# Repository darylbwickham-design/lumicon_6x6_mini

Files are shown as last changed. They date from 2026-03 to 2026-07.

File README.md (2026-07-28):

# Lumi-Con 6×6 Matrix Mini v1.1.0

A 36-key open-source stream controller with an integrated ST7735 TFT display, phone-first device setup, Lumia plugin support, and optional virtual pet features.

This project uses:

- a **Raspberry Pi Pico (RP2040)** to scan the 6×6 matrix
- an **ESP8266** to handle the TFT, Wi-Fi, HTTP API, and Lumia communication
- a **Lumia plugin** to receive key events, expose variables, and send display / pet actions back to the device

---

## What it does

### Inputs: device → Lumia

- The Pico scans all 36 keys and sends UART packets to the ESP8266.
- The ESP8266 converts those into Lumia-facing events:
  - **Short press:** `0–35`
  - **Long press:** `36–71` (`key + 36`)
- The ESP8266 posts events to the Lumia plugin listener.

### Display and pet control: Lumia → device

The ESP8266 exposes local HTTP endpoints so Lumia can send text, status updates, clear commands, health checks, and pet actions back to the device.

---

## Recommended current release set

Use this combination as the current baseline:

- **Pico firmware:** `6x6_test_pico.ino` or UF2 built from it
- **ESP firmware:** `lumicon_6x6_mini_v1_1_4.ino`
- **Lumia plugin:** `6x6_matrix_mini_v1_1_3.lumiaplugin`

### Plugin naming note

Older project history refers to the integrated plugin as **v5.2**. That package is effectively the **1.0.0** public baseline for the newer `6x6 matrix mini` plugin line.

If you are using the newer plugin packages, treat these as the current progression:

- `1.0.0` = old integrated `v5.2`
- `1.1.x` = newer `6x6 matrix mini` plugin line

---

## Main features

### Easy phone-based setup

On first boot, the ESP firmware can create a setup access point named **`Lumi-Con-Setup`**.

Use a mobile phone for first-time Wi-Fi setup, not the streaming PC or desktop browser. On your phone, connect to the setup Wi-Fi network, then tap the phone's Wi-Fi sign-in notification or open the phone's browser at:

`http://192.168.4.1`

From there you can join the device to your Wi-Fi network without editing the firmware source.

### Browser-based plugin host pairing

Once the device is already on your normal Wi-Fi network, you can set the Lumia/plugin host from any browser on the same network instead of recompiling the ESP sketch.

Use:

`http://<device-ip>/plugin?host=<pc-ip>`

This host is stored by the ESP and reused after reboot.

### TFT display actions

The Lumia plugin can send:

- **Display: Add Line**
- **Display: Set Status**
- **Display: Clear**

This is useful for:

- scene/status text
- alerts
- chat-style output
- debugging
- custom stream messages

### Virtual pet support

The platform includes an optional virtual pet system.

The current plugin supports these pet actions:

- `status`
- `sync`
- `feed`
- `play`
- `clean`
- `sleep`
- `med`
- `discipline`
- `reset`

The plugin also exposes pet variables for overlays, alerts, and automations.

### More reliable idle handling

The current plugin line performs a silent health check using `/status?silent=1` before marking the device offline, which helps avoid false disconnects when the device is simply idle.

### Multiple runtime modes

The current ESP firmware supports:

- **Chat mode**
- **noPet Debug mode**
- **Pet mode**
- **LCD Only Mode**

---

## Repository layout

At the time of writing, the public repository includes top-level folders for **3d files**, **Docs**, **Firmware**, and **Plugins/v5.2**. This README is written around the latest firmware and plugin files reviewed for this update, even where the live public repo still shows older packaging and README text. 

Recommended repo structure going forward:

- `Firmware/` for Pico and ESP firmware
- `Plugins/` for Lumia plugin packages and source
- `Docs/` for setup docs, changelogs, and release notes
- `3d files/` for enclosure and print assets

---

## Hardware overview

### Pico ↔ 6×6 matrix

The Pico scans the matrix.

Current Pico test firmware pin mapping:

#### Rows (inputs with pullups)
- `R0 -> GP12`
- `R1 -> GP1`
- `R2 -> GP2`
- `R3 -> GP3`
- `R4 -> GP4`
- `R5 -> GP5`

#### Columns (outputs)
- `C0 -> GP6`
- `C1 -> GP7`
- `C2 -> GP8`
- `C3 -> GP9`
- `C4 -> GP10`
- `C5 -> GP11`

### Pico → ESP8266 UART

- `Pico GP0 (TX) -> ESP RX / GPIO3`
- `Pico GND -> ESP GND`
- Optional: `1k` resistor in series on the TX line

### ESP8266 → ST7735 TFT (SPI)

Current ESP firmware pin mapping:

- `TFT VCC -> 3V3`
- `TFT GND -> GND`
- `TFT SCK -> D5 / GPIO14`
- `TFT MOSI -> D7 / GPIO13`
- `TFT CS -> D2 / GPIO4`
- `TFT DC -> D1 / GPIO5`
- `TFT RST -> ESP RST` recommended

### Important flashing note

Disconnect `Pico GP0 (TX) -> ESP RX (GPIO3)` while uploading firmware to the ESP8266.

---

## Arduino IDE setup

### 1) Install Arduino IDE

Download from:

`https://www.arduino.cc/en/software`

### 2) Add board manager URLs

In Arduino IDE, open:

`File -> Preferences -> Additional Boards Manager URLs`

Add:

#### ESP8266
`http://arduino.esp8266.com/stable/package_esp8266com_index.json`

#### Pico / RP2040 (Earle Philhower)
`https://github.com/earlephilhower/arduino-pico/releases/download/global/package_rp2040_index.json`

### 3) Install board packages

Open:

`Tools -> Board -> Boards Manager`

Install:

- **ESP8266 by ESP8266 Community**
- **Raspberry Pi Pico/RP2040 by Earle Philhower**

### 4) Install required libraries for the ESP8266 firmware

Install through **Sketch -> Include Library -> Manage Libraries**:

- **WiFiManager**
- **Adafruit GFX Library**
- **Adafruit ST7735 and ST7789 Library**

The Pico test firmware does not require extra third-party Arduino libraries beyond the RP2040 board package.

---

## Flashing the firmware

### 1) Flash the Pico

Flash your current Pico matrix-scanner firmware first.

If you use a UF2 build:

1. Hold **BOOTSEL** while plugging the Pico into USB
2. The Pico appears as a USB drive
3. Drag and drop the UF2 file

If you use source:

- Open `6x6_test_pico.ino`
- Select your Pico board
- Upload normally

### 2) Flash the ESP8266

1. Disconnect `Pico GP0 -> ESP RX`
2. Open `lumi_con_esp_integrated_0_4_2.ino`
3. Select the correct ESP8266 board
4. Upload the firmware
5. Reconnect `Pico GP0 -> ESP RX`

---

## First-time device setup

### Step 1: connect the ESP to Wi-Fi

1. Power the device
2. On your mobile phone, open Wi-Fi settings and connect to the access point:
   - **`Lumi-Con-Setup`**
3. Tap the phone's Wi-Fi sign-in notification. If it does not appear, open the phone's browser and go to:
   - **`http://192.168.4.1`**
4. Select your Wi-Fi network and enter the password
5. Save
6. The ESP reboots and the display shows its IP address

Use the phone for this captive-portal step. A desktop or streaming PC browser is more likely to stay on your normal network and miss the device setup page.

### Step 2: install and configure the Lumia plugin

Install the current Lumia plugin package.

Recommended current plugin:

- `6x6_matrix_mini_v1_1_3.lumiaplugin`

In Lumia plugin settings:

- **Enable Listener**: `ON`
- **Listen Port**: `8787`
- **Shared Secret**: blank unless you intentionally set one in firmware
- **ESP Base URL**: set this to your device address, for example:
  - `http://192.168.1.50`

Recommended defaults:

- **ESP UI Mode**: `legacy_get`
- **Status Path**: `/status`
- **Pet Path**: `/pet`

### Step 3: pair the device with the plugin host

After phone Wi-Fi setup is finished and the device shows its IP address, run this from a browser on the same network:

`http://<device-ip>/plugin?host=<pc-ip>`

Example:

`http://192.168.1.50/plugin?host=192.168.1.87`

This tells the ESP where the Lumia plugin listener is running.

### Step 4: confirm the device is responding

Useful test URLs:

- `http://<device-ip>/health`
- `http://<device-ip>/plugin`
- `http://<device-ip>/msg?t=Hello`
- `http://<device-ip>/status?t=OK`
- `http://<device-ip>/clear`
- `http://<device-ip>/pet?action=status`

---

## Current HTTP API

The current ESP firmware supports these user-facing routes:

- `GET /`
- `GET /msg?t=...`
- `GET /status?t=...`
- `GET /status?silent=1`
- `GET /clear`
- `POST /ui`
- `GET /health`
- `GET /plugin`
- `GET /plugin?host=<pc-ip>`
- `GET /plugin?clear=1`
- `GET /pet?action=status|sync|feed|play|clean|sleep|med|toggleSleep|discipline|reset`

---

## Boot behavior and modes

Current boot-key behavior in the ESP firmware:

- Hold **Pico key 0** at boot -> reset Wi-Fi settings and restart
- Hold **Pico key 1** at boot -> Chat mode
- Hold **Pico key 2** at boot -> noPet Debug mode
- Hold **Pico key 35** at boot -> Pet mode

Current runtime modes include:

- **Chat mode**
- **noPet Debug mode**
- **Pet mode**
- **LCD Only Mode**

---

## Lumia plugin: what it adds

### Alerts

The current plugin provides:

- **6x6 short**
- **6x6 long**
- **Pet**

### Actions

The current plugin provides:

- **Display: Add Line**
- **Display: Set Status**
- **Display: Clear**
- **Pet Action**

### Useful variables

The plugin exposes device and pet variables, including:

- `{{event}}`
- `{{kind}}`
- `{{key_label}}`
- `{{held_ms}}`
- `{{device_id}}`
- `{{device_ip}}`
- `{{device_rssi}}`
- `{{device_connected}}`
- `{{device_status_text}}`
- `{{pet_stage_name}}`
- `{{pet_hunger}}`
- `{{pet_happiness}}`
- `{{pet_health}}`
- `{{pet_poop}}`
- `{{pet_change_name}}`

---

## Quick usage ideas

- Use **Display: Set Status** for stream state text such as `LIVE`, `BRB`, or scene names.
- Use **Display: Add Line** for scrolling messages, redeems, or now-playing text.
- Use **Pet Action -> status** before updating a pet overlay.
- Use **Pet Action -> sync** after reconnecting the device.
- Use **Pet Action -> clean** when a pet event indicates poop-related state changed.

---

## Troubleshooting

### ESP upload fails

Disconnect `Pico GP0 (TX) -> ESP RX (GPIO3)` while flashing the ESP8266.

### The setup AP does not appear

- Reboot the device
- Use the factory reset boot key path if Wi-Fi credentials need clearing
- Make sure the ESP firmware actually flashed successfully

### TFT stays white or blank

- Check TFT power and SPI wiring
- Wire `TFT RST -> ESP RST`
- If colours are wrong, check the ST7735 tab/init settings in firmware

### Lumia receives nothing

- Make sure the plugin listener is enabled
- Confirm the plugin listen port is `8787` unless intentionally changed
- Confirm the ESP host pairing was set with:
  - `http://<device-ip>/plugin?host=<pc-ip>`
- Confirm the PC and device are on the same LAN

### Lumia can receive key events but cannot send text or pet commands

- Set **ESP Base URL** in plugin settings to the device address
- Check `/health` and `/status` in a browser on the same network after phone setup is complete
- Confirm the device IP did not change after a reboot

### The plugin looks “offline” after idle time

The current plugin line performs one silent health check first. If you still see offline behavior:

- confirm **ESP Base URL** is correct
- confirm **Status Path** is `/status`
- confirm the device responds to:
  - `http://<device-ip>/status?silent=1`

---

## Summary

**Lumi-Con 6×6 Matrix Mini is a 36-key open-source stream controller with an integrated TFT display, phone-first Wi-Fi setup, Lumia plugin support, virtual pet features, and flexible display/status workflows for streams and automations.**

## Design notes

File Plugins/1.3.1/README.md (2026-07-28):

# Lumi-Con 6×6 Mini v1.1.1 — display repair

This is a focused repair for the 1.1 display build. It preserves the existing
hardware wiring, display rotation, Pico packet protocol, key numbers, web
endpoints, EEPROM layout and Lumia listener port.

## What changed

- Celebrations now draw their card once, then update only their moving details.
  The old version cleared and repainted the whole 160×128 TFT every 45 ms,
  which produced the visible black sweep/flash and choppy movement.
- Confetti and Success use animated particles in the unused top and bottom
  bands. Pulse uses a small centred pulse bar. None of those frames redraw the
  message card or the whole TFT.
- The opening frame is drawn immediately when `/celebrate` is called, so the
  browser test button and Lumia action give visible feedback as soon as the
  request arrives.
- The complete normal screen is restored afterwards. This fixes the Pet-mode
  header being blank after a full-screen celebration.
- The matched Lumia plugin verifies the device's JSON confirmation before it
  reports a successful celebration.

## Files

- `Firmware/lumicon_6x6_mini_v1_1_1.ino` — ESP8266 firmware source.
- `Plugin/matrix_6x6_mini_v11-1.3.1.lumiaplugin` — update to the separate
  `matrix_6x6_mini_v11` plugin created for the 1.1 firmware. It does not
  overwrite the original `matrix_6x6_mini` plugin.

## Test after flashing

1. After phone Wi-Fi setup is complete, open the controller address in a
   browser on the same network and run Confetti, Pulse and Success from
   **Test Celebrations**.
2. Each effect should appear immediately, animate without whole-screen black
   flashes, and return to a complete Chat or Pet screen.
3. Run the Lumia **Display: Celebration** action. A bad address, old firmware
   or missing endpoint now reports an error in Lumia instead of a false success.
4. Press a physical key while an effect is playing and confirm its normal Lumia
   key event still arrives.

## Build target

Compile for **LOLIN(WEMOS) D1 mini (clone)** using ESP8266 core **3.1.2** with
WiFiManager, Adafruit GFX and Adafruit ST7735 installed. Flash at offset
`0x000000` as with the previous firmware.

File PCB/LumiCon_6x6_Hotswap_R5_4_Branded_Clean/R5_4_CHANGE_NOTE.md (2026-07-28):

# Lumi-Con 6×6 Matrix Mini R5.4

This revision changes silkscreen only.

## Changes from R5.3

- Increased the 24 J1 pin labels on F.SilkS and B.SilkS from 0.70 mm to 0.80 mm.
- Increased the rear `TOP` label from 0.70 mm to 0.80 mm.
- Increased the rear `J1 PIN 1 = C0` label from 0.70 mm to 0.80 mm.
- Updated the printed revision from R5.3 to R5.4.

Copper, nets, tracks, vias, pads, footprints, drill holes, board outline, mounting holes and component placement are unchanged from the electrically clean R5.3 board.

The supplied DRC report for R5.3 showed:

- 0 unconnected pads
- 0 footprint errors
- 26 silkscreen text-height warnings

R5.4 addresses exactly those 26 warnings. Run KiCad DRC once more before Gerber export to confirm a zero-warning result in your local KiCad version.

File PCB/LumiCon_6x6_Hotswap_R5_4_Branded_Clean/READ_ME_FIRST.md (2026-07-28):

# Lumi-Con 6x6 Matrix Mini R5.3 Branded

This revision is electrically identical to the DRC-clean R5.2 board. Only silkscreen artwork and labels were added.

## Added to front silkscreen

- Simplified monochrome Lumi-Con matrix icon derived from `source_Lumi-Con.png`
- Monochrome `6X6 MATRIX MINI` wordmark derived from `source_6X6_MATRIX_MINI.png`
- `R5.3` revision mark
- J1 pin labels: `C0 R0 C1 R1 C2 R2 C3 R3 C4 R4 C5 R5`

## Added to back silkscreen

- Product/revision identification
- Mirrored J1 pin labels so the connector can be wired from either side
- J1 pin-1 note

## Mechanical

The four existing mounting holes remain unchanged:

- 3.2 mm NPTH clearance holes for M3 screws
- centres: (37.5,37.5), (162.5,37.5), (37.5,162.5), (162.5,162.5) mm in KiCad coordinates

## Before ordering

Open `LumiCon_6x6_Hotswap_R5_3_Branded.kicad_pro`, run KiCad DRC, and inspect both silkscreen layers in the 3D viewer/Gerber viewer. The artwork is confined to the top margin and does not alter copper, pads, drills, or board outline.

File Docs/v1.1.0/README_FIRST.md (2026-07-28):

# Lumi-Con 6×6 Matrix Mini 1.1

This is the compatibility-first upgrade from the supplied 1.0 release.

## What to install

1. Flash `Firmware/ESP8266/FLASH_THIS_lumicon_6x6_mini_v1.1.0.bin` to the
   D1 mini clone at address `0x000000`.
2. Install `Plugin/matrix_6x6_mini-1.3.0.lumiaplugin` in Lumia.
3. Leave the Pico firmware alone unless it needs restoring. Its source and UF2
   are included and remain protocol-compatible with 1.0.
4. Reboot the controller and follow the on-screen boot selector.

Existing Wi-Fi credentials, plugin-host configuration and pet data use the
same EEPROM layout and should survive an ordinary firmware upgrade.

## First Wi-Fi setup

Use a mobile phone, not the streaming PC:

1. Connect the phone to `Lumi-Con-Setup`.
2. Tap the phone's Wi-Fi sign-in notification.
3. If the sign-in page does not open, browse to `192.168.4.1`.
4. Select the normal home/streaming Wi-Fi network and enter its password.

Holding K0 during boot deliberately erases the saved Wi-Fi settings and opens
this setup flow immediately. It no longer makes you sit through a second full
boot before the phone setup screen appears.

## Visible boot controls

Key numbering is row-major: K0 is top-left and K35 is bottom-right.

| Hold during the boot menu | Result |
| --- | --- |
| K0 — top-left | Erase saved Wi-Fi and open phone setup |
| K1 — second key on the top row | Chat mode (also the default) |
| K2 — third key on the top row | noPet diagnostics |
| K35 — bottom-right | Virtual pet mode |

The progress bar must fill before a selection is accepted. If no key is held,
the controller enters Chat mode.

## New in 1.1

- The boot-options page is now actually shown.
- Phone-first Wi-Fi instructions are explicit on the TFT.
- Polished panels, badges, feed cards and wipe transitions replace the crude
  text-only presentation.
- New non-blocking `Confetti`, `Pulse`, and `Success` celebrations.
- Quick, standard, and big-moment celebration lengths.
- Lumia plugin action: **Display: Celebration**.
- Lumia plugin action: **Device: Screen Mode** switches Chat, Pet, and
  Diagnostics at runtime without a reboot.
- A responsive controller panel is available by opening the IP shown on the
  TFT. It can change screen mode, test every celebration, test messages/status,
  clear the feed, and open diagnostic JSON.
- The pet HUD now rotates through all four information pages; the previous
  health/discipline page was unreachable.
- The existing 0–71 key events, 72–93 pet events, endpoints, port 8787,
  display rotation, wiring and pet storage remain compatible.

Read `Docs/UPGRADE_AND_TEST.md` before treating the build as production-tested
on physical hardware. `Docs/BUILD_VALIDATION.md` records the completed compile,
plugin routing, archive, and hardware-integrity checks.

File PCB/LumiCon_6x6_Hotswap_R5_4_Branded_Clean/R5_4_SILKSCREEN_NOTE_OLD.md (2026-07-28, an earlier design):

# R5.3 silkscreen pre-check

- Parentheses balanced: YES
- Electrical object counts unchanged from R5.2: YES

- `(segment` count: 413
- `(via` count: 48
- `(pad` count: 340
- `(footprint` count: 77
- `(net` count: 49

- Front artwork bounds: x 42.0–121.84 mm, y 34.55–39.77 mm
- J1 labels centred at y 39.15 mm, below the header pads.
- No copper, drill, pad, footprint, net, segment, via, or Edge.Cuts objects were modified.

Native KiCad DRC remains the final check.

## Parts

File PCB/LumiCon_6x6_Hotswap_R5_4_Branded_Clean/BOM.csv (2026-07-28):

References | Qty | Value | Footprint | Side
SW1-SW36 | 36 | Kailh CPG151101S11 hot-swap socket | SW_Hotswap_Kailh_1.00u | Bottom
D1-D36 | 36 | 1N4148W | D_SOD-123 | Bottom
J1 | 1 | 1x12 2.54 mm header | PinHeader_1x12_P2.54mm | Through-hole

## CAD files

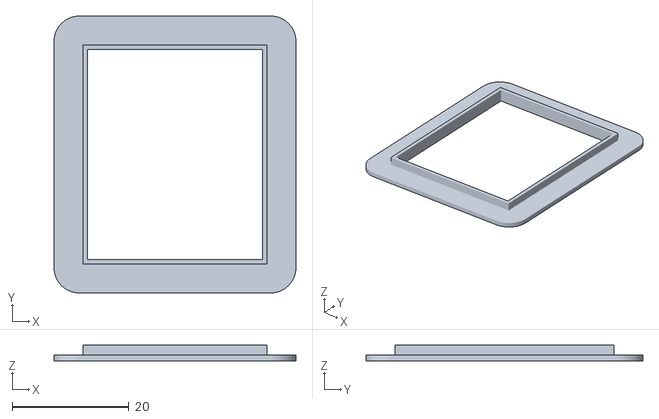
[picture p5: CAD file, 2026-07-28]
3d files/lcd bezel.stl
41.5 x 47.5 x 2.70

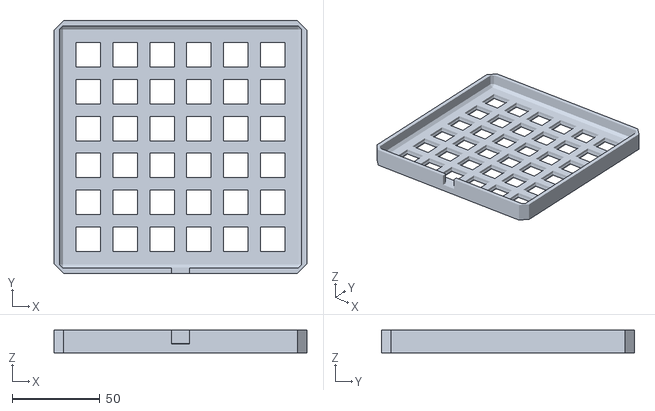
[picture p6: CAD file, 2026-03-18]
PCB/LumiCon_6x6_Hotswap_R5_4_Branded_Clean/6X6 Front V2_reference.stl
144.0 x 144.0 x 13.0

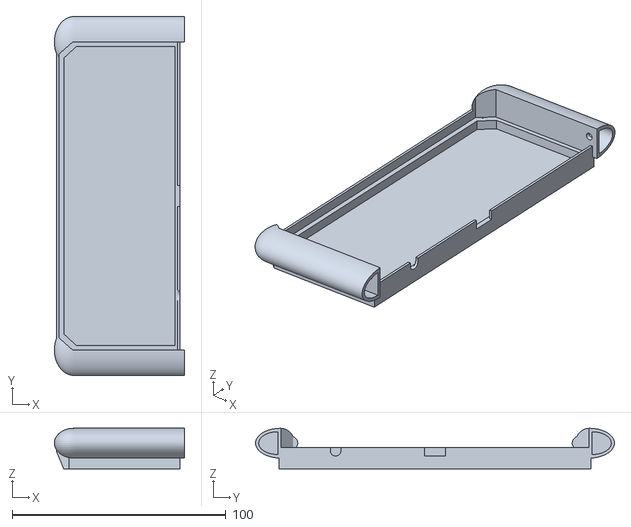
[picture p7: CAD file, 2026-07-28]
3d files/electronics rear v4.stl
61.0 x 168.0 x 19.0

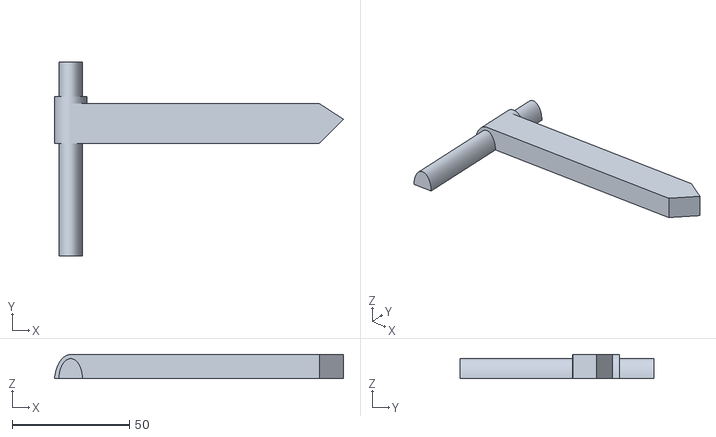
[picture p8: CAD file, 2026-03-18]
3d files/connector leg v2.stl
123.3 x 82.7 x 10.2

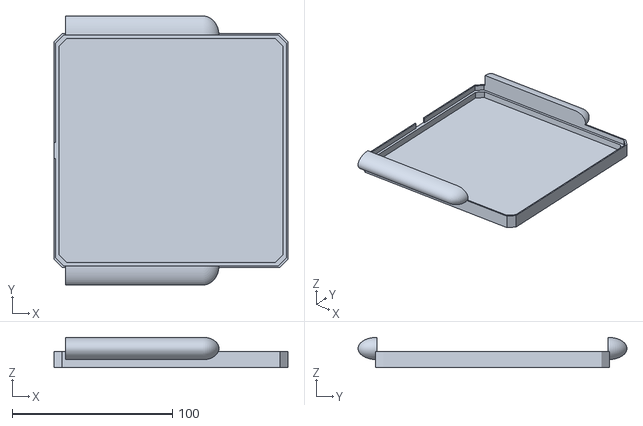
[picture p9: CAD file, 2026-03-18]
3d files/6X6 Rear v2.stl
146.0 x 168.0 x 19.0

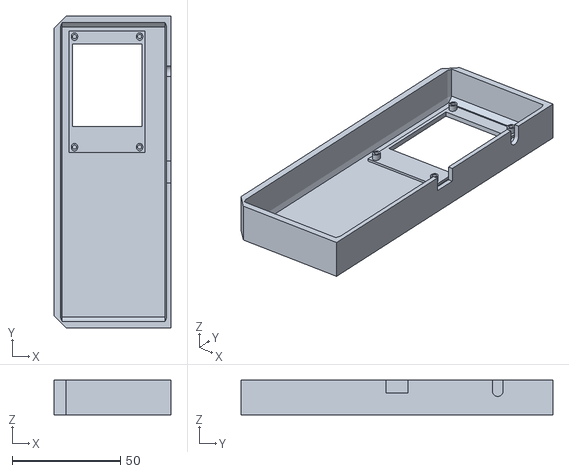
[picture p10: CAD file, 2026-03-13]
3d files/electronics front with lcd v2.stl
54.0 x 144.0 x 16.0

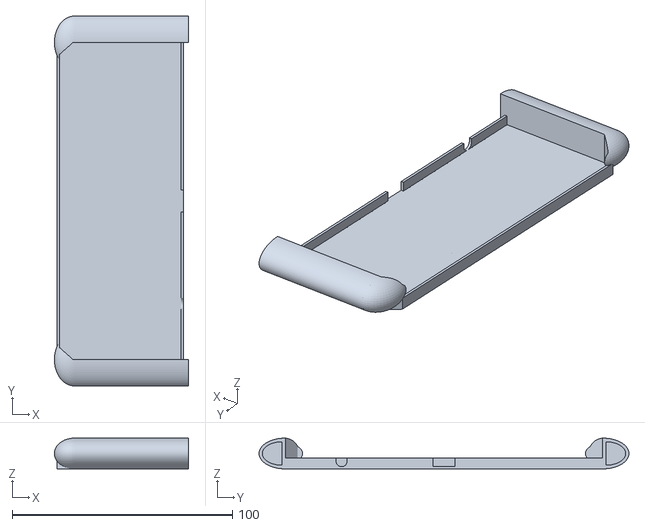
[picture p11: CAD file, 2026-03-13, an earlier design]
3d files/electronics rear v2.stl
61.0 x 168.0 x 14.0

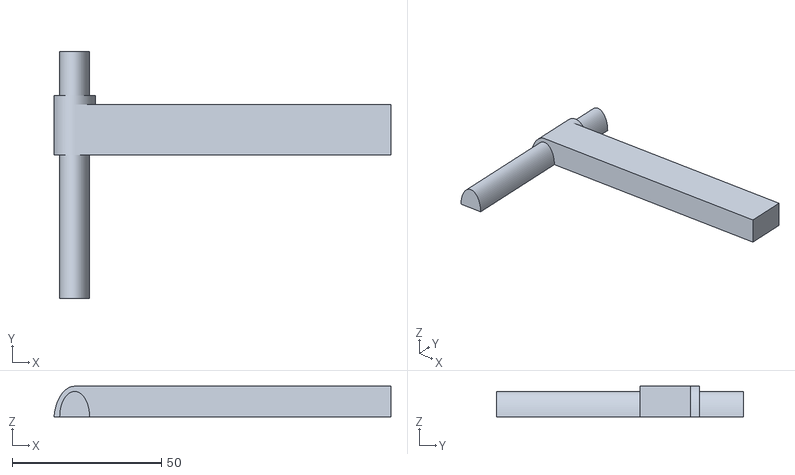
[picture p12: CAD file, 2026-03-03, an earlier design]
3d files/connector leg.stl
112.8 x 82.7 x 10.2

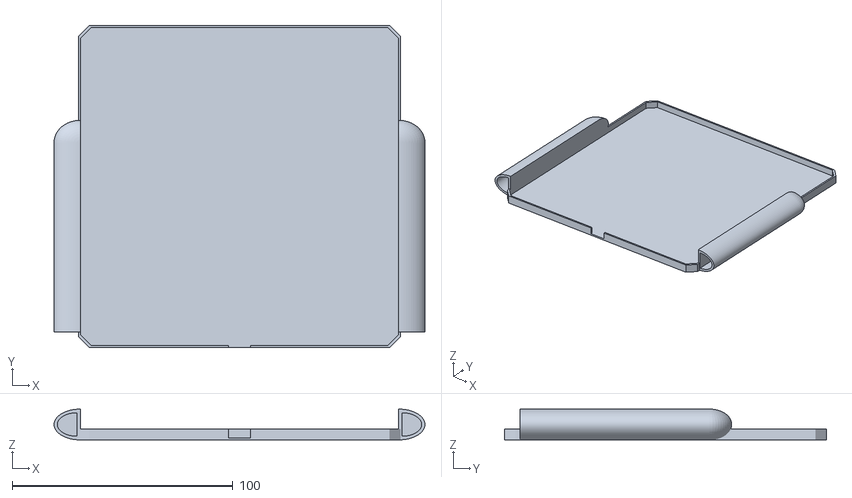
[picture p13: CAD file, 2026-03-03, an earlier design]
3d files/6X6 Rear.stl
168.0 x 146.0 x 14.0

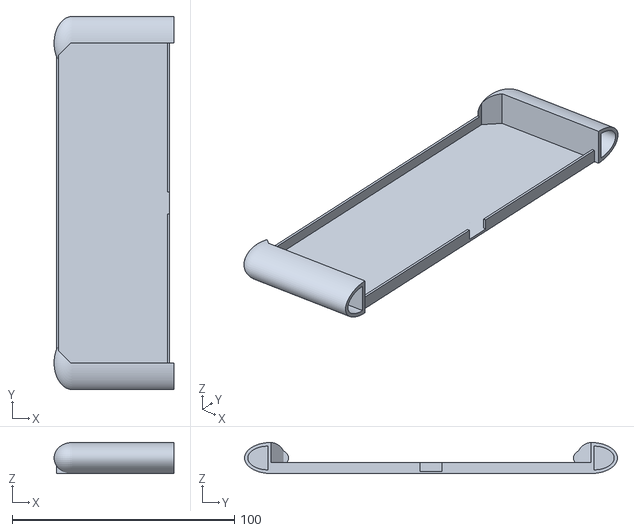
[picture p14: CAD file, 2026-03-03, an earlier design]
3d files/electronics rear.stl
54.0 x 168.0 x 14.0

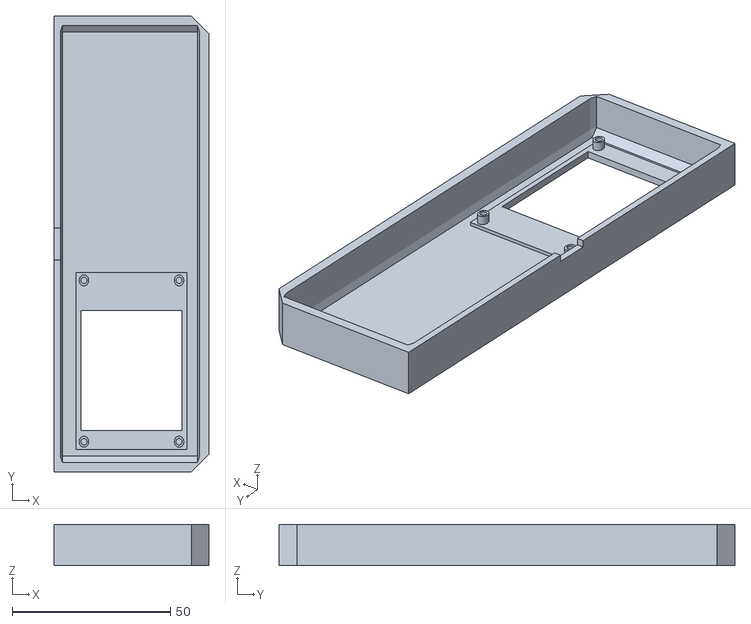
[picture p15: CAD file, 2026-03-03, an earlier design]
3d files/electronics front with lcd.stl
49.0 x 144.0 x 13.0

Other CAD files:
3d files/6X6 Front.stl
3d files/electronics rear v3.stl

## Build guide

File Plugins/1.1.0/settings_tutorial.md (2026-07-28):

# 6×6 Matrix Mini — Setup

36 key open source stream controller with integrated LCD, chat, alerts, and virtual pet support.

## Build files
GitHub repository:
https://github.com/darylbwickham-design/lumicon_6x6_mini

## Tutorial video
https://www.youtube.com/watch?v=UeyQVr_ehtY&list=PLqOF0QEQ86SRTQ2jzz_a06AIdHnLY1Pae

## Quick checklist
1. Install the plugin in Lumia.
2. Download and flash the firmware from the GitHub repo.
3. Power the device and complete Wi-Fi setup with a mobile phone, not the streaming PC:
   - connect the phone to `Lumi-Con-Setup`
   - tap the phone's Wi-Fi sign-in notification, or open the phone's browser at `192.168.4.1`
   - enter your normal Wi-Fi details on the phone setup page
4. In plugin settings, enable the listener and confirm the port.
5. If your device shows a mode prompt on boot: select Confirmed mode for best reliability.

## Virtual pet
This plugin version also supports a Lumi-Con virtual pet, including pet alerts, status variables for overlays, and pet control actions.

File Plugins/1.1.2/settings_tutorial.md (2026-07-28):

# 6×6 Matrix Mini — Setup

36 key open source stream controller with integrated LCD, chat, alerts, and virtual pet support.

## Build files
GitHub repository:
https://github.com/darylbwickham-design/lumicon_6x6_mini

## Tutorial video
https://www.youtube.com/watch?v=UeyQVr_ehtY&list=PLqOF0QEQ86SRTQ2jzz_a06AIdHnLY1Pae

## Quick checklist
1. Install the plugin in Lumia.
2. Download and flash the firmware from the GitHub repo.
3. Power the device and complete Wi‑Fi setup with a mobile phone, not the streaming PC:
   - connect the phone to `Lumi-Con-Setup`
   - tap the phone's Wi-Fi sign-in notification, or open the phone's browser at `192.168.4.1`
   - enter your normal Wi-Fi details on the phone setup page
4. In plugin settings, turn **Enable Listener** on.
5. Leave **Listen Port** as `8787` unless your firmware uses a different port.
6. If you set a secret in firmware, enter the same value in **Shared Secret**.
7. If you want Lumia to send text or pet commands back to the device, set **ESP Base URL** to your device address, for example:
   - `http://192.168.1.50`
8. Leave **ESP UI Mode** as `legacy_get` unless your firmware is using `/ui` POST mode.
9. Optional:
   - fill in **Key labels (Short 0–35)**
   - fill in **Key labels (Long 0–35)**
   These labels become `{{key_label}}` inside Lumia.

## What the plugin listens for
- **6×6 short press**
  - event `0` to `35`
- **6×6 long press**
  - event `36` to `71`
- **Pet events**
  - event base `72`
  - event count `22`

## Alerts added by the plugin
- **6x6 short**
  - Use this for normal short presses on the matrix.
  - Add a variation and choose the key number you want.
- **6x6 long**
  - Use this for long presses on the matrix.
  - Add a variation and choose the key number you want.
- **Pet**
  - Use this for virtual pet changes sent by the ESP firmware.
  - Add a variation and choose the pet update you want.

### Pet variations
- `hunger_up`
- `hunger_down`
- `happiness_up`
- `happiness_down`
- `energy_up`
- `energy_down`
- `hygiene_up`
- `hygiene_down`
- `health_up`
- `health_down`
- `discipline_up`
- `discipline_down`
- `poop_up`
- `poop_down`
- `stage_up`
- `stage_down`
- `sleep_on`
- `sleep_off`
- `sick_on`
- `sick_off`
- `alive_on`
- `alive_off`

## Device variables
These update automatically when the device talks to Lumia.

### Matrix / key variables
- `{{event}}` — key number
- `{{kind}}` — `short` or `long`
- `{{key_label}}` — label from plugin settings
- `{{held_ms}}` — press duration in milliseconds
- `{{received_at}}` — when Lumia received the event

### Device status variables
- `{{device_id}}`
- `{{device_ip}}`
- `{{device_rssi}}`
- `{{device_connected}}`
- `{{device_last_seen}}`
- `{{device_status_text}}`
- `{{seq}}`

Use these for:
- support/debug overlays
- online/offline indicators
- signal strength displays
- status text panels

## Pet variables
These can be used in overlays, alert text, and commands.

### Pet change variables
- `{{pet_change_name}}`
- `{{pet_change_code}}`
- `{{pet_variation}}`
- `{{pet_field_id}}`
- `{{pet_field_name}}`
- `{{pet_from}}`
- `{{pet_to}}`
- `{{pet_delta}}`

### Pet state variables
- `{{pet_ui_mode}}`
- `{{pet_mode_enabled}}`
- `{{pet_alive}}`
- `{{pet_stage}}`
- `{{pet_stage_name}}`
- `{{pet_age_minutes}}`
- `{{pet_hunger}}`
- `{{pet_happiness}}`
- `{{pet_energy}}`
- `{{pet_hygiene}}`
- `{{pet_health}}`
- `{{pet_discipline}}`
- `{{pet_poop}}`
- `{{pet_sick}}`
- `{{pet_sleeping}}`
- `{{pet_event_base}}`
- `{{pet_event_count}}`
- `{{pet_queue_depth}}`
- `{{pet_last_change_code}}`

### Good uses for variables
- Overlay text:
  - `Hunger: {{pet_hunger}}`
  - `Stage: {{pet_stage_name}}`
  - `Poops: {{pet_poop}}`
  - `Status: {{device_status_text}}`
- Alert messages:
  - `Pet update: {{pet_change_name}}`
  - `{{pet_field_name}} changed from {{pet_from}} to {{pet_to}}`
- Display text:
  - `Pet Stage: {{pet_stage_name}}`
  - `RSSI {{device_rssi}}`

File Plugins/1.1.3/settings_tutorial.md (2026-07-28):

# 6×6 Matrix Mini — Setup

36 key open source stream controller with integrated LCD, chat, alerts, and virtual pet support.

## Build files
GitHub repository:
https://github.com/darylbwickham-design/lumicon_6x6_mini

## Tutorial video
https://www.youtube.com/watch?v=UeyQVr_ehtY&list=PLqOF0QEQ86SRTQ2jzz_a06AIdHnLY1Pae

## Quick checklist
1. Install the plugin in Lumia.
2. Download and flash the amended firmware.
3. Power the device and complete Wi-Fi setup with a mobile phone, not the streaming PC:
   - connect the phone to `Lumi-Con-Setup`
   - tap the phone's Wi-Fi sign-in notification, or open the phone's browser at `192.168.4.1`
   - enter your normal Wi-Fi details on the phone setup page
4. In plugin settings, turn **Enable Listener** on.
5. Leave **Listen Port** as `8787` unless your firmware uses a different port.
6. If you set a secret in firmware, enter the same value in **Shared Secret**.
7. If you want Lumia to send text or pet commands back to the device, set **ESP Base URL** to your device address, for example:
   - `http://192.168.1.50`
8. Leave **ESP UI Mode** as `legacy_get` unless your firmware is using `/ui` POST mode.
9. Optional:
   - fill in **Key labels (Short 0–35)**
   - fill in **Key labels (Long 0–35)**
   These labels become `{{key_label}}` inside Lumia.
10. Optional:
   - turn on **Show advanced settings**
   - confirm **Status Path** is `/status`
   - confirm **Offline Timeout (seconds)** is set how you want

## Silent health-check behavior
- The plugin does **not** immediately mark the device offline just because the idle timeout elapsed.
- After **Offline Timeout**, the plugin performs one silent health check to:
  - `/status?silent=1`
- If the device replies successfully, Lumia keeps the device connected.
- Lumia only marks the device offline if that health check fails.

## What the plugin listens for
- **6×6 short press**
  - event `0` to `35`
- **6×6 long press**
  - event `36` to `71`
- **Pet events**
  - event base `72`
  - event count `22`

## Alerts added by the plugin
- **6x6 short**
  - Use this for normal short presses on the matrix.
  - Add a variation and choose the key number you want.
- **6x6 long**
  - Use this for long presses on the matrix.
  - Add a variation and choose the key number you want.
- **Pet**
  - Use this for virtual pet changes sent by the ESP firmware.
  - Add a variation and choose the pet update you want.

### Pet variations
- `hunger_up`
- `hunger_down`
- `happiness_up`
- `happiness_down`
- `energy_up`
- `energy_down`
- `hygiene_up`
- `hygiene_down`
- `health_up`
- `health_down`
- `discipline_up`
- `discipline_down`
- `poop_up`
- `poop_down`
- `stage_up`
- `stage_down`
- `sleep_on`
- `sleep_off`
- `sick_on`
- `sick_off`
- `alive_on`
- `alive_off`

## Device variables
These update automatically when the device talks to Lumia.

### Matrix / key variables
- `{{event}}` — key number
- `{{kind}}` — `short` or `long`
- `{{key_label}}` — label from plugin settings
- `{{held_ms}}` — press duration in milliseconds
- `{{received_at}}` — when Lumia received the event

### Device status variables
- `{{device_id}}`
- `{{device_ip}}`
- `{{device_rssi}}`
- `{{device_connected}}`
- `{{device_last_seen}}`
- `{{device_status_text}}`
- `{{seq}}`

Use these for:
- support/debug overlays
- online/offline indicators
- signal strength displays
- status text panels

## Pet variables
These can be used in overlays, alert text, and commands.

### Pet change variables
- `{{pet_change_name}}`
- `{{pet_change_code}}`
- `{{pet_variation}}`
- `{{pet_field_id}}`
- `{{pet_field_name}}`
- `{{pet_from}}`
- `{{pet_to}}`
- `{{pet_delta}}`

### Pet state variables
- `{{pet_ui_mode}}`
- `{{pet_mode_enabled}}`
- `{{pet_alive}}`
- `{{pet_stage}}`
- `{{pet_stage_name}}`
- `{{pet_age_minutes}}`
- `{{pet_hunger}}`
- `{{pet_happiness}}`
- `{{pet_energy}}`
- `{{pet_hygiene}}`
- `{{pet_health}}`
- `{{pet_discipline}}`
- `{{pet_poop}}`
- `{{pet_sick}}`
- `{{pet_sleeping}}`
- `{{pet_event_base}}`
- `{{pet_event_count}}`
- `{{pet_queue_depth}}`
- `{{pet_last_change_code}}`

### Good uses for variables
- Overlay text:
  - `Hunger: {{pet_hunger}}`
  - `Stage: {{pet_stage_name}}`
  - `Poops: {{pet_poop}}`
  - `Status: {{device_status_text}}`
- Alert messages:
  - `Pet update: {{pet_change_name}}`
  - `{{pet_field_name}} changed from {{pet_from}} to {{pet_to}}`
- Display text:
  - `Pet Stage: {{pet_stage_name}}`
  - `RSSI {{device_rssi}}`

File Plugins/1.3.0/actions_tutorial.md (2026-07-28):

# Actions (TFT + Pet + Connect) — Plugin 1.3.0 / Firmware 1.1

If you set **ESP Base URL**, Lumia can send commands back to the device.

## Device: Connect
Use this to register the current PC with the device again.

The plugin now retries automatically after ordinary outages. This manual action remains useful when diagnosing a changed network or forcing an immediate retry.

What it sends:
- `http://<device-ip>/plugin?host=<pc-ip>`

Best for:
- phone setup retry after Wi-Fi or network changes
- reconnecting after network changes
- forcing the device to refresh which PC it should talk to

Input:
- none

## Device: Screen Mode
Switch the live TFT between:

- **Chat** — normal Lumia message/feed view
- **Pet** — animated persistent virtual pet
- **Diagnostics** — key delivery and ACK-focused feed

The switch is immediate and does not reboot the controller or alter event
numbers. Firmware 1.1 briefly confirms the selected mode on screen.

## Display actions

### Display: Add Line
Use this to send a new line into the device message/chat area.

Best for:
- event logs
- chat relay
- now playing text
- custom Lumia messages

Input:
- **Message**

Examples:
- `Now Playing: {{song_title}}`
- `{{username}} redeemed hydrate`
- `Pet update: {{pet_change_name}}`

### Display: Set Status
Use this to set the main status line on the device.

Best for:
- stream state
- scene name
- timer or mode text
- pet state

Input:
- **Message**
- **Status Color**
  - `Default (Teal)` — used when unset
  - `Red`
  - `Yellow`
  - `Green`

Accepted status inputs:
- `GET /status?t=REC%20STARTED&color=red`
- `GET /status?t=REC%20STARTED&color=green`
- `GET /status?t=REC%20STARTED&color=yellow`
- `POST /ui` with `{"channel":"status","text":"REC STARTED","color":"green"}`
- If **Status Color** is left on **Default (Teal)**, the plugin sends no color override and the device uses its default teal status color.

Examples:
- Message: `LIVE` | Status Color: `Red`
- Message: `Scene: BRB` | Status Color: `Yellow`
- Message: `Pet sleeping` | Status Color: `Green`
- Message: `Stage: {{pet_stage_name}}` | Status Color: `Default (Teal)`

### Display: Clear
Use this to clear the device display.

Best for:
- resetting the screen
- clearing old messages
- blanking before a new mode or section

Input:
- none

### Display: Celebration
Use this for follows, raids, milestones, wins, successful actions, or any Lumia
event that deserves stronger on-device feedback.

Input:
- **Celebration Text**
- **Style** — Confetti, Pulse, or Success
- **Accent Colour** — Teal, Green, Gold, Red, or Pink
- **Length** — Quick, Standard, or Big Moment

The animation is non-blocking: key events and the Lumia listener continue to
run while it is visible.

## Pet Action
Use this to control the virtual pet or request a fresh status update from the device.

### Pet Action options
- `status`
- `sync`
- `feed`
- `play`
- `clean`
- `sleep`
- `med`
- `discipline`
- `reset`

## Silent health checks
The plugin also uses the device status endpoint for connection verification:
- after the idle timeout, Lumia performs a silent health check with `/status?silent=1`
- this check is meant to be silent on the device
- Lumia only shows the device as disconnected if that health check fails
- while offline, registration and health checks retry automatically with a quiet backoff
- listener port errors are retried after the conflicting application releases the port

## Recommended ways to use the actions
- Use **Device: Connect** after changing Wi-Fi, router, or the PC network adapter.
- Use **Device: Screen Mode** when an action should move the device between its
  Chat, Pet, and Diagnostics views.
- Use **Display: Add Line** for scrolling information and short messages.
- Use **Display: Set Status** for one important line of text, with an optional status color.
- Use **Display: Clear** before changing modes or screens.
- Use **Pet Action -> status** before showing a pet overlay if you want the latest values.
- A status request updates pet state variables without changing the last real `pet_change_*` values.
- Use **Pet Action -> sync** after reconnecting the device.
- Use **Pet Action -> clean** when `poop_up` triggers.
- Use **Pet Action -> feed** or **play** from Lumia command buttons.

## Example Lumia setups

### Example 1 — Manual reconnect button
- Trigger: Lumia command button
- Action: **Device: Connect**

### Example 2 — Key press updates the status
- Trigger: **6x6 short**
- Variation: choose the key
- Action: **Display: Set Status**
- Message: `Pressed {{key_label}}`
- Status Color: `Default (Teal)`

### Example 3 — Recording warning
- Trigger: Lumia command button
- Action: **Display: Set Status**
- Message: `REC STARTED`
- Status Color: `Red`

### Example 4 — Pet overlay sync button
- Trigger: Lumia command button
- Action: **Pet Action**
- Pet Action value: `status`

### Example 5 — Auto clean after poop event
- Trigger: **Pet**
- Variation: `poop_up`
- Action: **Pet Action**
- Pet Action value: `clean`

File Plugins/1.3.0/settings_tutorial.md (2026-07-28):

# Lumi-Con 6×6 Mini — Setup v1.3.0 / Firmware 1.1

36 key open source stream controller with integrated LCD, chat, alerts, and virtual pet support.

## Quick checklist
1. Install the plugin in Lumia.
2. Download and flash the amended firmware.
3. Power the device and complete Wi-Fi setup with a mobile phone, not the streaming PC:
   - connect the phone to `Lumi-Con-Setup`
   - tap the phone's Wi-Fi sign-in notification, or open the phone's browser at `192.168.4.1`
   - enter your normal Wi-Fi details on the phone setup page
4. In plugin settings, enter **ESP Base URL** first, for example:
   - `http://192.168.1.50`
5. Click **Save**.
   - The plugin detects the local PC IP that reaches the device.
   - The plugin then calls:
     - `http://<device-ip>/plugin?host=<pc-ip>`
6. Turn **Enable Listener** on.
7. Leave **Listen Port** as `8787`. The supplied firmware has this port compiled into it.
8. Leave **Shared Secret** empty unless you have compiled the identical `PLUGIN_SECRET` into the firmware.
9. If needed later, run the **Device: Connect** action to send the host registration again.
10. Leave **ESP UI Mode** as `ui_post` with firmware 1.1. Select `legacy_get` only when using 1.0 firmware.
11. Optional:
   - fill in **Key labels (Short 0–35)**
   - fill in **Key labels (Long 0–35)**
   These labels become `{{key_label}}` inside Lumia.

## Display status color support
- **Display: Set Status** now includes a **Status Color** dropdown.
- Available colors:
  - `Default (Teal)`
  - `Red`
  - `Yellow`
  - `Green`
- If no color is chosen, the device keeps its default teal status color.

## Display celebrations
- **Display: Celebration** plays a non-blocking full-screen animation.
- Styles: `Confetti`, `Pulse`, and `Success`.
- Accent colours: teal, green, gold, red, and pink.
- Lengths: Quick (1 second), Standard (1.8 seconds), and Big Moment (3 seconds).
- The key listener and HTTP server continue operating while the animation plays.

## Runtime screen switching
- Use **Device: Screen Mode** to select Chat, Pet, or Diagnostics.
- The controller does not reboot.
- The selected mode lasts until the next reboot; the boot default remains Chat
  unless a boot key is held.

## Built-in test panel
Open the ESP Base URL itself in a browser. Firmware 1.1 provides controls for
screen modes, all three celebrations, display/message tests, and JSON
diagnostics.

## Reliability repairs in v1.2.2
- Repeated firmware delivery attempts can no longer execute one physical press twice.
- A pet status request updates state without inventing a false `hunger_up` change.
- The listener recovers automatically after a port conflict is cleared.
- Offline devices are rechecked with a quiet exponential backoff.
- Firmware reboots reset event sequencing safely.
- Device event processing is parallelised so acknowledgements return more quickly.
- Timed-out HTTP requests are aborted instead of remaining open.

## What “Device: Connect” does
- Resolves the correct local PC IP for the selected device address
- Sends `GET /plugin?host=<pc-ip>` to the ESP Base URL
- Updates these variables:
  - `{{host_pc_ip}}`
  - `{{host_register_status}}`
  - `{{host_register_message}}`
  - `{{host_register_at}}`

## Health checks and automatic recovery
- The plugin does **not** immediately mark the device offline just because the idle timeout elapsed.
- After **Offline Timeout**, the plugin performs one silent health check to:
  - `/status?silent=1`
- If the device replies successfully, Lumia keeps the device connected.
- Lumia only marks the device offline if that health check fails.
- When the device is offline, the plugin automatically retries registration and health checks.
- Retry intervals gradually increase to avoid network spam and reset after recovery.
- If the listener port is occupied, the plugin reports the error and retries after the conflict is cleared.

## What the plugin listens for
- **6×6 short press**
  - event `0` to `35`
- **6×6 long press**
  - event `36` to `71`
- **Pet events**
  - event base `72`
  - event count `22`

## Alerts added by the plugin
- **6x6 short**
  - Use this for normal short presses on the matrix.
  - Add a variation and choose the key number you want.
- **6x6 long**
  - Use this for long presses on the matrix.
  - Add a variation and choose the key number you want.
- **Pet**
  - Use this for virtual pet changes sent by the ESP firmware.
  - Add a variation and choose the pet update you want.

### Pet variations
- `hunger_up`
- `hunger_down`
- `happiness_up`
- `happiness_down`
- `energy_up`
- `energy_down`
- `hygiene_up`
- `hygiene_down`
- `health_up`
- `health_down`
- `discipline_up`
- `discipline_down`
- `poop_up`
- `poop_down`
- `stage_up`
- `stage_down`
- `sleep_on`
- `sleep_off`
- `sick_on`
- `sick_off`
- `alive_on`
- `alive_off`

## Device variables

### Matrix / key variables
- `{{event}}` — key number
- `{{kind}}` — `short` or `long`
- `{{key_label}}` — label from plugin settings
- `{{held_ms}}` — press duration in milliseconds
- `{{received_at}}` — when Lumia received the event

### Device status variables
- `{{device_id}}`
- `{{device_ip}}`
- `{{device_rssi}}`
- `{{device_connected}}`
- `{{device_last_seen}}`
- `{{device_status_text}}`
- `{{seq}}`
- `{{listener_status}}`
- `{{listener_error}}`
- `{{listener_port}}`
- `{{firmware_plugin_port}}`
- `{{firmware_version}}`
- `{{device_free_heap}}`

### Host registration variables
- `{{host_pc_ip}}`
- `{{host_register_status}}`
- `{{host_register_message}}`
- `{{host_register_at}}`

Use these for:
- support or debug overlays
- online or offline indicators
- signal strength displays
- showing the registered PC IP
- showing whether the connect step succeeded

## Pet variables

### Pet change variables
- `{{pet_change_name}}`
- `{{pet_change_code}}`
- `{{pet_variation}}`
- `{{pet_field_id}}`
- `{{pet_field_name}}`
- `{{pet_from}}`
- `{{pet_to}}`
- `{{pet_delta}}`

Pet state requests do not overwrite these change variables. They retain the last real pet transition.

### Pet state variables
- `{{pet_ui_mode}}`
- `{{pet_mode_enabled}}`
- `{{pet_alive}}`
- `{{pet_stage}}`
- `{{pet_stage_name}}`
- `{{pet_age_minutes}}`
- `{{pet_hunger}}`
- `{{pet_happiness}}`
- `{{pet_energy}}`
- `{{pet_hygiene}}`
- `{{pet_health}}`
- `{{pet_discipline}}`
- `{{pet_poop}}`
- `{{pet_sick}}`
- `{{pet_sleeping}}`
- `{{pet_event_base}}`
- `{{pet_event_count}}`
- `{{pet_queue_depth}}`
- `{{pet_last_change_code}}`

## Good uses for variables
- Overlay text:
  - `Hunger: {{pet_hunger}}`
  - `Stage: {{pet_stage_name}}`
  - `Poops: {{pet_poop}}`
  - `Status: {{device_status_text}}`
  - `Host: {{host_pc_ip}}`
- Alert messages:
  - `Pet update: {{pet_change_name}}`
  - `{{pet_field_name}} changed from {{pet_from}} to {{pet_to}}`
- Display text:
  - `Pet Stage: {{pet_stage_name}}`
  - `RSSI {{device_rssi}}`

## Suggested test for the new status color feature
Create four **Display: Set Status** actions in Lumia and test:
1. Message: `REC STARTED` with **Status Color** = `Red`
2. Message: `BRB` with **Status Color** = `Yellow`
3. Message: `LIVE` with **Status Color** = `Green`
4. Message: `READY` with **Status Color** = `Default (Teal)`

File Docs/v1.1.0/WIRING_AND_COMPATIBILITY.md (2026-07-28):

# Wiring and compatibility — unchanged from 1.0

No STL, PCB copper, mounting-hole position or wiring change is required.

## Pico matrix

| Function | Pico GPIO |
| --- | --- |
| Row 0 | GP12 |
| Rows 1–5 | GP1–GP5 |
| Columns 0–5 | GP6–GP11 |
| UART TX to ESP RX | GP0 |

The PCB J1 order remains:

`C0, R0, C1, R1, C2, R2, C3, R3, C4, R4, C5, R5`

Key numbering is physical row-major: top row K0–K5, second row K6–K11,
through bottom row K30–K35.

## Pico to ESP8266

| Pico | ESP8266 D1 mini |
| --- | --- |
| GP0 UART TX | RX / GPIO3 |
| GND | GND |
| Power rail used by the existing build | Existing matching power input |

The UART signal is 3.3 V logic. Do not inject 5 V logic into ESP RX.

## TFT to ESP8266

| TFT function | D1 mini pin |
| --- | --- |
| CS | D2 / GPIO4 |
| DC | D1 / GPIO5 |
| SCLK | D5 / GPIO14 |
| MOSI | D7 / GPIO13 |
| RST | Existing fixed/shared reset arrangement (`-1` in firmware) |

The firmware remains `INITR_GREENTAB` with rotation `3`, matching the supplied
1.0 enclosure and bezel.

## Software compatibility

- Pico packet: `A5, type, key, xor` at 115200 baud.
- Short key events: 0–35.
- Long key events: 36–71.
- Pet events: 72–93.
- Lumia listener port: 8787.
- Existing `/msg`, `/status`, `/clear`, `/ui`, `/health`, `/plugin`, and
  `/pet` endpoints remain available.
- New endpoints: `/celebrate` and `/mode`.
- Opening `/` shows the firmware 1.1 device test and diagnostics panel.

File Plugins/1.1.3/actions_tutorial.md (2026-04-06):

# Actions (TFT + Pet)

If you set **ESP Base URL**, Lumia can send commands back to the device.

## Display actions

### Display: Add Line
Use this to send a new line into the device message/chat area.

Best for:
- event logs
- chat relay
- now playing text
- custom Lumia messages

Input:
- **Message**

Examples:
- `Now Playing: {{song_title}}`
- `{{username}} redeemed hydrate`
- `Pet update: {{pet_change_name}}`

### Display: Set Status
Use this to set the main status line on the device.

Best for:
- stream state
- scene name
- timer/mode text
- pet state

Input:
- **Message**

Examples:
- `LIVE`
- `Scene: BRB`
- `Pet sleeping`
- `Stage: {{pet_stage_name}}`

### Display: Clear
Use this to clear the device display.

Best for:
- resetting the screen
- clearing old messages
- blanking before a new mode or section

Input:
- none

## Pet Action

Use this to control the virtual pet or request a fresh status update from the device.

### Pet Action options
- **status**
  - asks the device for current pet values without changing anything
- **sync**
  - refreshes Lumia with the current pet state
- **feed**
  - feeds the pet
- **play**
  - plays with the pet
- **clean**
  - cleans the pet / clears poop-related state
- **sleep**
  - toggles or controls sleep depending on firmware behavior
- **med**
  - gives medicine
- **discipline**
  - disciplines the pet
- **reset**
  - resets the pet state

## Silent health checks
The plugin also uses the device status endpoint for connection verification:
- after the idle timeout, Lumia performs a silent health check with `/status?silent=1`
- this check is meant to be silent on the device
- Lumia only shows the device as disconnected if that health check fails

## Recommended ways to use the actions
- Use **Display: Add Line** for scrolling information and short messages.
- Use **Display: Set Status** for one important line of text.
- Use **Display: Clear** before changing modes or screens.
- Use **Pet Action -> status** before showing a pet overlay if you want the latest values.
- Use **Pet Action -> sync** after reconnecting the device.
- Use **Pet Action -> clean** when `poop_up` triggers.
- Use **Pet Action -> feed** or **play** from Lumia command buttons.

## Example Lumia setups

### Example 1 — Key press updates the display
- Trigger: **6x6 short**
- Variation: choose the key
- Action: **Display: Set Status**
- Message: `Pressed {{key_label}}`

### Example 2 — Pet overlay sync button
- Trigger: Lumia command button
- Action: **Pet Action**
- Pet Action value: `status`

### Example 3 — Auto clean after poop event
- Trigger: **Pet**
- Variation: `poop_up`
- Action: **Pet Action**
- Pet Action value: `clean`

### Example 4 — Send pet state to the display
- Action: **Display: Add Line**
- Message: `Mood {{pet_happiness}} | Poop {{pet_poop}}`

Full guide + updates:
https://github.com/darylbwickham-design/lumicon_6x6_mini

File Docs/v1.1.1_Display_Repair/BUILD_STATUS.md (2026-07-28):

# Build status

The firmware and plugin source were checked for archive integrity, JSON
validity, JavaScript syntax/loadability, manifest validity and balanced C++
braces. The final ZIP was extracted again and compared byte-for-byte with its
source firmware.

This workspace did not contain the ESP8266 3.1.2 platform or its Xtensa
toolchain, and its restricted network could not fetch them. Consequently this
package deliberately contains the corrected flash source and matched plugin,
but not a newly compiled `.bin`. Compile it using the target named in
`README.md` before flashing hardware.

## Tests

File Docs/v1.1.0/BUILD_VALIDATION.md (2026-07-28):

# Build validation — Lumi-Con 6×6 Mini 1.1

## ESP8266 firmware

- Board target: `esp8266com:esp8266:d1_mini_clone`
- ESP8266 board core: `3.1.2`
- Result: clean compile completed with all sketch warnings enabled
- Flash binary: `476,144` bytes
- Global/static RAM: `35,700 / 80,192` bytes (`44%`)
- IRAM: `60,395 / 65,536` bytes (`92%`, including the fixed 32 KiB
  instruction-cache reservation reported by the ESP8266 build)
- Flash code: `437,092 / 1,048,576` bytes (`41%`)

Libraries used:

| Library | Version |
| --- | --- |
| WiFiManager | 2.0.17 |
| Adafruit GFX Library | 1.12.1 |
| Adafruit BusIO | 1.17.2 |
| Adafruit ST7735 and ST7789 Library | 1.11.0 |
| ESP8266WiFi / WebServer / HTTPClient / EEPROM / SPI / Wire | ESP8266 core 3.1.2 bundled versions |

The matching ELF and map files are in `Firmware/ESP8266/debug/` for stack
decoding and support work. They are not required for flashing.

## Lumia plugin

- Plugin manifest version: `1.3.0`
- Lumia target: `^9.0.0`
- SDK dependency: `@lumiastream/plugin 0.9.0`
- Manifest parsed and passed the SDK validator with zero errors.
- `main.js` passed Node syntax checking.
- A mock-controller integration test confirmed the exact routes and bodies for:
  - Device: Screen Mode
  - Display: Celebration, including duration
  - Display: Add Line
  - Display: Set Status
  - Display: Clear
  - Pet Action: Status

## Compatibility/integrity

- All seven supplied STL files are byte-identical to the 1.0 release.
- The complete PCB directory is byte-identical to the 1.0 release.
- The Pico UF2 and source are byte-identical to the 1.0 release.
- Existing short events `0–35`, long events `36–71`, pet events `72–93`,
  UART packet format, port `8787`, EEPROM layout, TFT pins, tab type, and
  rotation are unchanged.

## Firmware hashes

| File | SHA-256 |
| --- | --- |
| `FLASH_THIS_lumicon_6x6_mini_v1.1.0.bin` | `5636342b89f6cd6db258172839e325411e7f1e8c68be52819f5e47d1987ef46d` |
| `rollback/lumi_con_esp_integrated_1_0_4.ino.bin` | `7505e4bc7d8a3d14d46622c88c239665d2ab5864cd03486a642ba85bf84b96c3` |
| `Pico/6x6_matrix_pico_v1_0/6x6_matrix_pico_v1_0.uf2` | `1cf1ededb351b8376ee2fd855a11ce8195c9260ff06f8657dac9c4c5414bdb0c` |
| `Plugin/matrix_6x6_mini-1.3.0.lumiaplugin` | `47922abda2b52680853b6616d934d1afe096ee5b67a9420231fa3332ea45a1be` |

Compilation and software-side validation cannot substitute for the physical
acceptance checklist in `UPGRADE_AND_TEST.md`.

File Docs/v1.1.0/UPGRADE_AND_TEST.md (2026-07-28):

# Upgrade and test procedure — 1.1

## Back up / rollback

The supplied 1.0 binary is included at:

`Firmware/ESP8266/rollback/lumi_con_esp_integrated_1_0_4.ino.bin`

Flashing that binary at `0x000000` restores the previous ESP firmware. An
ordinary firmware flash does not intentionally erase EEPROM. Do not select an
erase-all option unless you also intend to remove saved Wi-Fi and pet state.

## ESP flash

Target: **LOLIN(WEMOS) D1 mini (clone)**, ESP8266 core 3.1.2.

With esptool:

```powershell
py -m esptool --chip esp8266 --port COMx --baud 460800 write_flash 0x000000 FLASH_THIS_lumicon_6x6_mini_v1.1.0.bin
```

Replace `COMx` with the controller's serial port. The binary can also be used
by the existing Lumi-Con web flasher if that flasher accepts a complete
ESP8266 sketch binary at offset zero.

## Lumia

1. Install `matrix_6x6_mini-1.3.0.lumiaplugin`.
2. Set **ESP Base URL** to the IP shown on the controller, including `http://`.
3. Leave the listener enabled and port at `8787`.
4. Leave **ESP UI Mode** on `UI POST`.
5. Save, then run **Device: Connect** if registration does not complete
   automatically.
6. Open the IP shown on the TFT in a browser to use the built-in device test
   panel.

## Required physical test

- [ ] Screen remains landscape with the existing enclosure/bezel.
- [ ] Logo, welcome and boot selector appear in sequence.
- [ ] K0/K1/K2/K35 highlight their full row and show hold progress.
- [ ] No key held enters Chat mode.
- [ ] With Wi-Fi erased, the display says to use a mobile phone.
- [ ] Choosing K0 reaches phone setup without repeating the logo sequence.
- [ ] Phone captive portal completes and the assigned IP appears.
- [ ] Short presses deliver events 0–35 exactly once.
- [ ] Long presses deliver events 36–71 exactly once.
- [ ] ACK OK/FAIL changes correctly without freezing the display.
- [ ] Display Message, Status, Clear and Celebration actions work.
- [ ] Quick, Standard and Big Moment celebration lengths differ visibly.
- [ ] Confetti, Pulse and Success animations do not stop key delivery.
- [ ] Device: Screen Mode switches Chat/Pet/Diagnostics without rebooting.
- [ ] Browser panel loads from the displayed IP and its test controls work.
- [ ] Pet mode loads existing state and pet actions still work.
- [ ] Pet HUD eventually shows health and discipline values.
- [ ] Reboot preserves Wi-Fi, plugin host and pet state.

## Acceptance rule

Do not call a unit passed after a screen-only check. Test all 36 keys once,
then long-press at least K0, K17 and K35, and confirm Lumia received the
expected event numbers without duplicates.

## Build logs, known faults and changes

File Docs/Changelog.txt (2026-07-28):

## Versioning notes

* **ESP firmware:** the **filename is the correct public version**. Internal header version strings are ignored where they conflict.
* **Plugin:** `lumi_con_bridge_integrated_v5_2` should be treated as **plugin version `1.0.0`**.

---

# ESP Firmware Changelog

### 0_0_1

* Initial integrated ESP8266 firmware baseline.
* Added ST7735 TFT display support.
* Added HTTP display endpoints: `/msg`, `/status`, and `/clear`.
* Added `POST /ui` for browser or plugin-driven text updates.
* Added Pico UART packet input for button events.
* Added Lumia event posting for short and long press actions.
* Added WiFiManager-based Wi-Fi setup.

### 0_0_3

* Refined the display layout with a two-line header structure.
* Improved transient status and prompt handling.
* Added immediate redraw when temporary header text expires.
* Added LED blink feedback on received press packets.
* Added blocking mode selection after Wi-Fi connection.
* Added `/health` endpoint.

### 0_0_4

* Improved rendering performance and general UI cleanup.
* Kept runtime behavior aligned with `0_0_3`.
* Retained the mode-selection flow.
* Updated the TFT reset pin arrangement used by this build.

### 0_1_0

* Introduced the integrated pet system.
* Added EEPROM-backed save data with validation and CRC.
* Added pet animation and stat rendering.
* Added `/pet` endpoint support.
* Added Lumia-linked pet change event scaffolding.
* Added direct onboard pet-button controls.
* Reworked the codebase into a more structured tutorial-style layout.

### 0_1_1

* Continued refinement of the new pet firmware branch.
* Retained pet simulation, persistence, rendering, and Lumia-linked event support.
* Improved overall structure and maintainability.

### 0_1_2

* Continued iteration on the integrated pet firmware.
* Retained the EEPROM-backed pet system and Lumia-linked control flow.
* Focused on stability and internal cleanup.

### 0_1_3

* Continued refinement of the pet-focused firmware branch.
* Preserved the existing pet simulation and rendering model.
* Focused on incremental polish and cleanup.

### 0_2_0

* Began transition toward Lumia-first pet control.
* Retained the pet system, EEPROM persistence, and `/pet` endpoint.
* Reduced emphasis on direct onboard pet interaction.

### 0_2_1

* Moved further into the Lumia-only pet control model.
* Retained pet state change events with telemetry values for Lumia use.
* Added boot-time pet disable behavior.
* Added boot-time Wi-Fi reset behavior.

### 0_2_2

* Introduced mode-based runtime behavior.
* Added **Chat mode**.
* Added **noPet Debug mode**.
* Retained Lumia-only pet control.
* Moved mode selection into boot behavior.

### 0_2_3

* Iterated on the new mode-based runtime branch.
* Retained Chat mode, noPet Debug mode, and the Lumia pet control path.
* Focused on cleanup and minor runtime refinement.

### 0_2_4

* Added the branded boot presentation flow.
* Standardized boot order to:

  * Lumi-Con logo
  * 6x6 Matrix Mini logo
  * Welcome screen
  * Boot options screen
* Established the boot flow used by later versions.

### 0_2_5

* Continued the branded boot-flow branch.
* Preserved the runtime structure introduced in `0_2_4`.
* Focused on small cleanup and continuity.

### 0_2_6

* Expanded and consolidated the integrated firmware branch.
* Retained Chat mode, noPet Debug mode, pet support, EEPROM persistence, and branded boot flow.
* Marked a larger internal integration step ahead of later UI polish work.

### 0_2_7

* Restored the intended boot splash assets.
* Preserved the broader runtime behavior from the prior integrated branch.
* Focused on correcting the boot presentation.

### 0_3_0

* Set **Chat mode** as the default runtime mode.
* Hid **Pet mode** unless explicitly selected at boot.
* Froze pet behavior unless pet mode is actively selected.
* Preserved the branded boot flow.
* Began a `0_3_x` series focused mainly on pet rendering and boot-logo polish.

### 0_3_1

* Refined boot-mode handling and documentation.
* Added explicit hidden pet-mode boot selection on key `35`.
* Retained Chat mode as the default runtime path.
* Preserved the branded boot flow.

### 0_3_2

* Continued polish on the `0_3_x` branch.
* Focused mainly on pet rendering tweaks and boot/logo presentation refinement.
* Retained the hidden pet-mode model and default Chat mode.

### 0_3_3

* Continued polish on the `0_3_x` branch.
* Focused mainly on pet rendering tweaks and boot/logo presentation refinement.
* Retained the existing runtime structure.

### 0_3_4

* Continued `0_3_x` polish work.
* Improved Wi-Fi setup screen wording.
* Retained Chat mode as default and hidden pet mode on boot key `35`.
* Continued refining pet rendering and boot/logo presentation.

### 0_3_5

* Continued `0_3_x` polish work.
* Refined text rendering calls to reduce unnecessary background-color redraw behavior in text output paths.
* Retained the existing runtime structure, default Chat mode, and hidden pet mode.
* Continued polishing Wi-Fi setup wording, pet rendering, and boot/logo presentation.

### 0_3_6

* Continued `0_3_x` polish work.
* Retained the Wi-Fi setup text improvements from the prior build.
* Reworked event POST payload construction from repeated `String` concatenation to a fixed buffer with `snprintf`, improving the event-send path.
* Preserved the existing runtime model, default Chat mode, and hidden pet mode.

### 0_4_0

* Added browser-settable plugin host configuration with `GET /plugin`.
* Added support for setting the plugin host from a browser query, for example `/plugin?host=192.168.1.50`.
* Added support for clearing the saved plugin host with `/plugin?clear=1`.
* Moved plugin host storage into EEPROM so it persists across reboot.
* Updated `/health` to report the active plugin host and port.
* Switched event posting to use the configured plugin host instead of a source-hardcoded host.

### 0_4_1

* Added silent health-probe support on `/status` to help prevent disconnects after idle periods.
* Changed `/status` to return structured JSON status data instead of simple plain-text acknowledgement.
* Added support for `silent=1` so health checks can avoid forcing visible UI interruptions.
* Included device metadata in `/status`, including device ID, IP, RSSI, sequence counter, and firmware version.
* Retained browser-configurable plugin host support and EEPROM-backed host persistence.

### 0_4_2

* Expanded the firmware beyond the earlier `0_4_1` health-probe update.
* Added **LCD Only Mode** as an additional runtime mode.
* Added special serial packet handling for entering LCD Only Mode and requesting pet status broadcasts.
* Added serial transmission of pet snapshot/status data for secondary-device integration.
* Ignored normal keypad events while LCD Only Mode is active.
* Updated pet timing so timers stay in sync while the pet is paused outside active pet modes.
* Replaced the plain-text root endpoint with a simple HTML API landing page.
* Expanded `/health` with free-heap and formatted uptime reporting.
* Expanded mode reporting to include `lcdOnly`.
* Refined the Wi-Fi setup presentation, including the AP name `Lumi-Con-Setup` and clearer phone-browser instructions for `http://192.168.4.1`.

### 1.1.4

* Added a new `lumicon_6x6_mini_v1_1_4` firmware source entry based on the supplied `1.1.3` sketch.
* Bumped the firmware version constants from `1.1.3` to `1.1.4`.
* Tightened the on-device Wi-Fi setup wording to say `phone browser` and `No desktop browser`.
* Kept the phone-first setup flow, including `Lumi-Con-Setup`, the phone sign-in popup, and the `192.168.4.1` fallback address.
* Added a compiled `FLASH_THIS_lumicon_6x6_mini_v1.1.4.bin` build for LOLIN(WEMOS) D1 mini (clone).

---

# Lumia Plugin Changelog

### 1.0.0

* Initial stable integrated Lumia plugin baseline.
* Added listener support for Lumi-Con device events.
* Added short and long press handling for the 6×6 matrix.
* Added device status variables for overlays, alerts, and debugging.
* Added TFT display actions for message, status, and clear operations.
* Added sequence dedupe handling to avoid repeated event processing.
* Fixed sequence dedupe after device reboot so events resume correctly after the ESP restarts.
* Included status, offline, and toast support in the integrated plugin branch.

### 1.1.0

* Renamed and repackaged the plugin as **6x6 matrix mini**.
* Expanded the plugin from matrix-only behavior into a fuller device plugin covering LCD, chat, alerts, and virtual pet support.
* Added pet event support with event range beginning at `72`.
* Added pet variables for overlays, alerts, and automation use.
* Added **Pet Action** support for status, sync, feed, play, clean, sleep, medicine, discipline, and reset.
* Added `petPath` advanced setting for ESP pet endpoint configuration.
* Updated debug toast wording to include pet-related activity.
* Expanded tutorials/settings references to external markdown files inside the plugin package.

### 1.1.1

* Refined the plugin manifest and alert definitions.
* Simplified pet alert variation metadata.
* Kept runtime behavior aligned with `1.1.0`.
* No core listener or action logic changes detected in `main.js`.

### 1.1.2

* Improved sequence handling for incoming device events.
* Changed duplicate detection so exact repeated sequence values are ignored cleanly.
* Reset sequence tracking when a lower sequence value is received, improving recovery after device-side counter changes.
* Greatly expanded the bundled setup and actions documentation.
* Added fuller documentation for key events, pet variables, device variables, and example Lumia setups.

### 1.1.3

* Added silent health-check support using the device status endpoint.
* Changed the idle/offline flow so the plugin performs a silent `/status?silent=1` check before marking the device offline.
* Added in-flight protection for the offline probe.
* Added helpers for base URL, timeout, and status-path handling.
* Updated unload behavior to silently clear device-connected state.
* Updated settings help text to document silent health checks and their dependency on the ESP base URL.
* Updated action and settings tutorials to explain the new health-check behavior.

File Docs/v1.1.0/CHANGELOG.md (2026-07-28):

# Changelog

## Firmware 1.1.0

- Fixed the missing boot-options presentation.
- Added explicit K1 Chat selection, physical key-position hints, selected-row
  highlighting, and live hold progress.
- Extended the visible selection window to 4.2 seconds.
- Replaced generic Wi-Fi browser instructions with phone-first setup steps.
- Removed the unnecessary second full boot after choosing K0 Wi-Fi setup.
- Added connecting, connected, IP-address, and setup-timeout result screens.
- Added dark captive-portal styling.
- Added polished welcome, status, message-feed and wait screens.
- Added wipe transitions between boot stages.
- Added non-blocking Confetti, Pulse and Success celebrations.
- Added 0.6–5 second configurable celebration duration.
- Added `GET /celebrate` and `POST /ui` celebration support.
- Added `GET /mode` for safe runtime Chat, Pet, and Diagnostics switching.
- Replaced the old Pet API link list with a responsive device control,
  celebration-test, display-test, and diagnostics panel.
- Added READY and plugin-linked success feedback.
- Fixed the pet HUD rotation so health/discipline is no longer skipped.
- Preserved the 1.0 hardware, protocol, event numbers, endpoints and EEPROM.

## Lumia plugin 1.3.0

- Added **Display: Celebration**.
- Added style and accent-colour controls.
- Added Quick, Standard, and Big Moment duration choices.
- Added **Device: Screen Mode** for runtime Chat/Pet/Diagnostics switching.
- Made `UI POST` the default for new firmware 1.1 installations.
- Retained Legacy GET support for firmware 1.0.

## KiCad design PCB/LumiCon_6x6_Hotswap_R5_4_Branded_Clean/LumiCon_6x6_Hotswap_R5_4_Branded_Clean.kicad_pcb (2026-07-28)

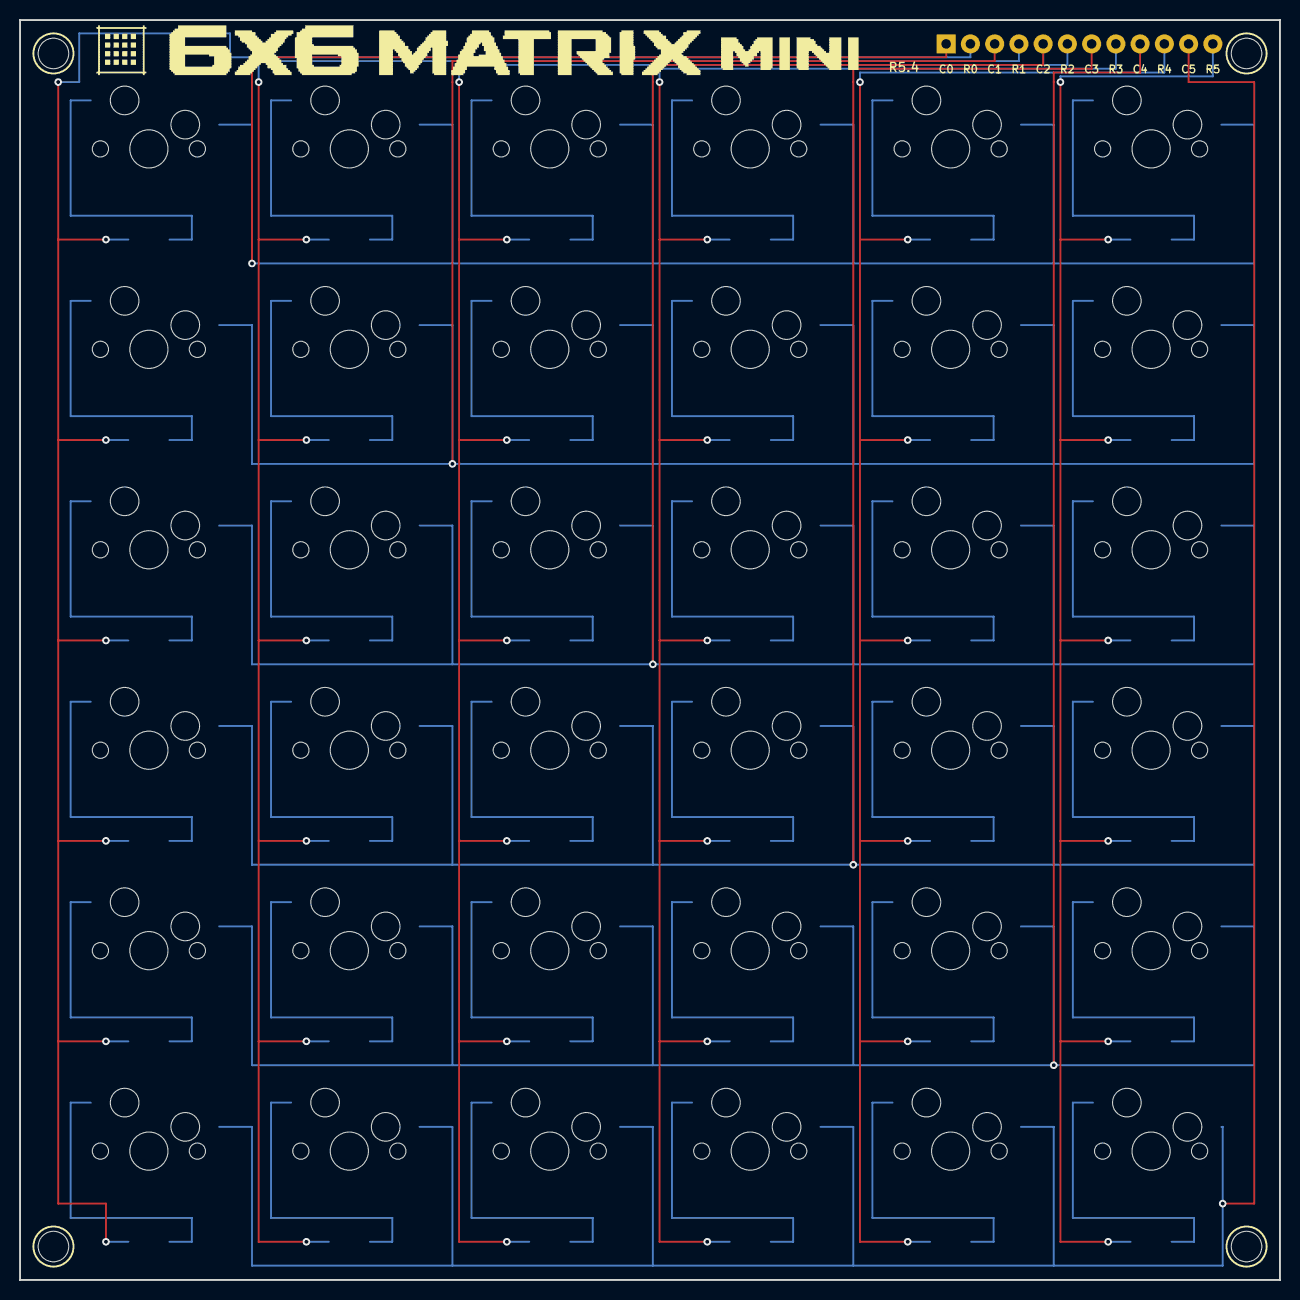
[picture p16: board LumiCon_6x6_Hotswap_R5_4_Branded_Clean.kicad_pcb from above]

Board: 2 copper layers, 132.0 x 132.0 mm, 77 parts (0 on the bottom side), 48 nets.

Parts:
D1, D2, D3, D4, D5, D6, D7, D8, D9, D10, D11, D12, D13, D14, D15, D16, D17, D18, D19, D20, D21, D22, D23, D24, D25, D26, D27, D28, D29, D30, D31, D32, D33, D34, D35, D36: 1N4148W; D_SOD-123
H1, H2, H3, H4: MountingHole_3.2mm_M3
J1: MATRIX_1x12; PinHeader_1x12_P2.54mm
SW1, SW2, SW3, SW4, SW5, SW6, SW7, SW8, SW9, SW10, SW11, SW12, SW13, SW14, SW15, SW16, SW17, SW18, SW19, SW20, SW21, SW22, SW23, SW24, SW25, SW26, SW27, SW28, SW29, SW30, SW31, SW32, SW33, SW34, SW35, SW36: Kailh_CPG151101S11; SW_Hotswap_Kailh_1.00u

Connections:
COL0: J1.1, SW1.1, SW2.1, SW3.1, SW4.1, SW5.1, SW6.1
COL1: J1.3, SW7.1, SW8.1, SW9.1, SW10.1, SW11.1, SW12.1
COL2: J1.5, SW13.1, SW14.1, SW15.1, SW16.1, SW17.1, SW18.1
COL3: J1.7, SW19.1, SW20.1, SW21.1, SW22.1, SW23.1, SW24.1
COL4: J1.9, SW25.1, SW26.1, SW27.1, SW28.1, SW29.1, SW30.1
COL5: J1.11, SW31.1, SW32.1, SW33.1, SW34.1, SW35.1, SW36.1
K00_D: D1.1, SW1.2
K01_D: D7.1, SW7.2
K02_D: D13.1, SW13.2
K03_D: D19.1, SW19.2
K04_D: D25.1, SW25.2
K05_D: D31.1, SW31.2
K10_D: D2.1, SW2.2
K11_D: D8.1, SW8.2
K12_D: D14.1, SW14.2
K13_D: D20.1, SW20.2
K14_D: D26.1, SW26.2
K15_D: D32.1, SW32.2
K20_D: D3.1, SW3.2
K21_D: D9.1, SW9.2
K22_D: D15.1, SW15.2
K23_D: D21.1, SW21.2
K24_D: D27.1, SW27.2
K25_D: D33.1, SW33.2
K30_D: D4.1, SW4.2
K31_D: D10.1, SW10.2
K32_D: D16.1, SW16.2
K33_D: D22.1, SW22.2
K34_D: D28.1, SW28.2
K35_D: D34.1, SW34.2
K40_D: D5.1, SW5.2
K41_D: D11.1, SW11.2
K42_D: D17.1, SW17.2
K43_D: D23.1, SW23.2
K44_D: D29.1, SW29.2
K45_D: D35.1, SW35.2
K50_D: D6.1, SW6.2
K51_D: D12.1, SW12.2
K52_D: D18.1, SW18.2
K53_D: D24.1, SW24.2
K54_D: D30.1, SW30.2
K55_D: D36.1, SW36.2
ROW0: D1.2, D7.2, D13.2, D19.2, D25.2, D31.2, J1.2
ROW1: D2.2, D8.2, D14.2, D20.2, D26.2, D32.2, J1.4
ROW2: D3.2, D9.2, D15.2, D21.2, D27.2, D33.2, J1.6
ROW3: D4.2, D10.2, D16.2, D22.2, D28.2, D34.2, J1.8
ROW4: D5.2, D11.2, D17.2, D23.2, D29.2, D35.2, J1.10
ROW5: D6.2, D12.2, D18.2, D24.2, D30.2, D36.2, J1.12

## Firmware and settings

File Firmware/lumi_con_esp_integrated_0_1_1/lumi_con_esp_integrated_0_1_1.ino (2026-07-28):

/*
  ============================================================================
  Lumi-Con ESP8266 Pet Firmware
  ============================================================================
  Tutorial Edition / Readability Revision

  Hardware target
  ---------------------------------------------------------------------------
  - ESP8266 board
  - ST7735 SPI TFT display
  - Raspberry Pi Pico feeding key events over serial
  - 2 extra SPST buttons wired to the ESP for direct pet gameplay
  - Lumia plugin on the network for ACK events and pet-state change events

  What this firmware is trying to be
  ---------------------------------------------------------------------------
  This is not just “code that works”.
  This revision is written so you can OPEN the sketch and actually learn from it.

  The design goal is:
  1. Keep the firmware stable and non-blocking
  2. Keep RAM usage sensible for ESP8266
  3. Keep the display responsive by redrawing only what changes
  4. Keep save data resilient with validation and CRC
  5. Keep Lumia integration compact and easy to extend later

  Big architecture, in plain English
  ---------------------------------------------------------------------------
  There are five main jobs running side-by-side:

  1) Network/UI layer
     - Hosts a tiny web server
     - Lets Lumia or tools push messages/status to the header
     - Exposes /pet and /health endpoints

  2) Pico key event bridge
     - Reads packets from the Pico
     - Detects short vs long presses
     - Sends ACK events to the Lumia-side plugin

  3) Pet simulation
     - Tracks hunger, happiness, energy, hygiene, health, discipline
     - Advances age and stage over time
     - Handles sickness, sleep, poop, death, revive, discipline

  4) Pet rendering
     - Draws a small animated creature
     - Rotates stat views
     - Updates only changed areas when possible

  5) Persistence + fault tolerance
     - Saves to EEPROM with magic/version/CRC
     - Defers writes to avoid EEPROM wear
     - Uses wrap-safe millis() timing everywhere practical

  Lumia event model in this build
  ---------------------------------------------------------------------------
  - Key releases still generate the normal ACK/plugin events.
  - Pet state changes also generate a compact event packet.
  - That second channel is meant for a future Lumia plugin variable layer.
    Example: hunger went down, sleep turned on, sickness turned off, etc.

  Controls
  ---------------------------------------------------------------------------
  - Button A (D5): cycle current pet action
  - Button B (D6): perform current pet action
  - Hold A+B: reset the pet
  - Pico keys still operate as the main Lumia input source

  HTTP endpoints
  ---------------------------------------------------------------------------
    GET  /msg?t=Hello
    GET  /status?t=OK
    GET  /clear
    POST /ui {"channel":"chat|status|clear","text":"..."}
    GET  /health
    GET  /pet?action=status|sync|feed|play|clean|sleep|med|toggleSleep|discipline|reset

  Notes for future you
  ---------------------------------------------------------------------------
  - Buttons use INPUT_PULLUP, so pressed = LOW.
  - The sketch avoids full-screen redraw spam on the TFT.
  - The pet uses minute-scale simulation, but the UI animates every few hundred ms.
  - The code is split into tutorial-style sections so you can navigate fast.

  This revision also deliberately anticipates the next three likely expansions:
  1) richer Lumia-side pet telemetry and variable syncing
  2) a proper sprite/content pipeline instead of one hardcoded creature
  3) deeper gameplay balancing, personalities, and branching evolution

  Those systems are scaffolded below with tutorial comments and placeholder
  structures, even where the current runtime still uses the simpler build.

  ============================================================================
*/


#include <Arduino.h>
#include <ESP8266WiFi.h>
#include <ESP8266WebServer.h>
#include <WiFiManager.h>
#include <ESP8266HTTPClient.h>
#include <WiFiClient.h>
#include <EEPROM.h>

#include <Adafruit_GFX.h>
#include <Adafruit_ST7735.h>
#include <SPI.h>

// ============================================================================
// 1. CONFIGURATION
// ============================================================================
// Everything in this block is the “change me on purpose” zone.
// If you want to retarget pins, timings, plugin host details, or display setup,
// this is the first place to look.
// ============================================================================

// Lumia/plugin host that receives event JSON.
const char* PLUGIN_HOST = "192.168.1.87";
constexpr uint16_t PLUGIN_PORT = 8787;
const char* PLUGIN_SECRET = "";

// Serial speed used between the Pico and the ESP.
constexpr uint32_t PICO_BAUD = 115200;
// Number of keys coming from the Pico matrix firmware.
constexpr uint8_t KEY_COUNT = 36;
constexpr uint32_t LONG_PRESS_MS = 600;

constexpr uint8_t FACTORY_RESET_KEY = 0;
constexpr uint32_t FACTORY_RESET_HOLD_MS = 1200;
constexpr uint32_t FACTORY_RESET_WINDOW_MS = 2500;

// Some ESP8266 board packages provide friendly D-pin aliases (D1, D2, etc.)
// and some do not. These fallbacks make the sketch compile on both styles.
#ifndef D0
#define D0 16
#endif
#ifndef D1
#define D1 5
#endif
#ifndef D2
#define D2 4
#endif
#ifndef D3
#define D3 0
#endif
#ifndef D4
#define D4 2
#endif
#ifndef D5
#define D5 14
#endif
#ifndef D6
#define D6 12
#endif
#ifndef D7
#define D7 13
#endif
#ifndef D8
#define D8 15
#endif

// ST7735 SPI pin assignment.
#define TFT_CS   D2
#define TFT_DC   D1
#define TFT_RST  -1
#define ST7735_TAB INITR_GREENTAB

// Two local gameplay buttons connected directly to the ESP.
constexpr uint8_t BTN_A_PIN = D5;
constexpr uint8_t BTN_B_PIN = D6;
constexpr bool BTN_ACTIVE = LOW;
constexpr uint16_t BUTTON_DEBOUNCE_MS = 28;
constexpr uint16_t BUTTON_COMBO_HOLD_MS = 900;

// EEPROM budget reserved for this sketch.
constexpr uint16_t EEPROM_BYTES = 256;
constexpr uint32_t PET_MAGIC = 0x50455431UL; // PET1
constexpr uint16_t PET_VERSION = 4;

constexpr uint16_t SCREEN_W = 160;
constexpr uint16_t SCREEN_H = 128;
constexpr uint8_t TEXT_SIZE = 1;
constexpr uint8_t CHAR_W = 6;
constexpr uint8_t LINE_H = 8;
constexpr uint8_t MAX_COLS = SCREEN_W / CHAR_W; // 26

constexpr uint32_t HEADER_TOAST_MS = 2000;
constexpr uint32_t TEXT_PAGE_SHOW_MS = 2000;
constexpr uint8_t TEXT_PAGE_HISTORY_LINES = 15;
// Time constants for UI, simulation, save, and Wi-Fi servicing.
constexpr uint32_t GAME_TICK_MS = 1000;
constexpr uint32_t ANIM_TICK_MS = 350;
constexpr uint32_t STATUS_ROTATE_MS = 3500;
constexpr uint32_t SAVE_DEFER_MS = 4000;
constexpr uint32_t WIFI_RETRY_MS = 15000;

// Lumia pet-change events start here.
constexpr uint8_t PET_ALERT_BASE = 72;
constexpr uint8_t PET_CHANGE_EVENT_COUNT = 22;
constexpr uint8_t PET_CHANGE_QUEUE_SIZE = 24;
constexpr uint32_t PET_EVENT_MIN_GAP_MS = 70;

constexpr uint16_t COLOR_BG = ST77XX_BLACK;
constexpr uint16_t COLOR_FG = ST77XX_WHITE;
constexpr uint16_t COLOR_DIM = 0x7BEF;
constexpr uint16_t COLOR_ACCENT = ST77XX_CYAN;
constexpr uint16_t COLOR_WARN = ST77XX_YELLOW;
constexpr uint16_t COLOR_BAD = ST77XX_RED;
constexpr uint16_t COLOR_GOOD = ST77XX_GREEN;
constexpr uint16_t COLOR_PINK = 0xF81F;
constexpr uint16_t COLOR_BROWN = 0xA145;
constexpr uint16_t COLOR_SKY = 0x04FF;

constexpr uint8_t HEADER_LINES = 2;
constexpr uint8_t HEADER_H = HEADER_LINES * LINE_H;
constexpr uint8_t GAME_Y = HEADER_H;
constexpr uint8_t GAME_H = SCREEN_H - HEADER_H;

// Global device objects.
Adafruit_ST7735 tft(TFT_CS, TFT_DC, TFT_RST);
ESP8266WebServer server(80);
String deviceId;


// Forward declarations are written out manually so the Arduino auto-prototype
// generator does not guess and produce broken declarations for tutorial code
// that uses custom structs, enums, and references.
struct DebouncedButton;
struct PetSnapshot;
struct FuturePetTelemetryPacket;
enum PetAction : uint8_t;
enum PetTelemetryField : uint8_t;

PetTelemetryField telemetryFieldForChange(uint8_t changeCode);
static inline uint8_t petEventNumber(uint8_t code);
const char* petChangeName(uint8_t code);
FuturePetTelemetryPacket buildFutureTelemetryPacket(uint8_t code, uint8_t fromValue, uint8_t toValue, uint16_t ageMinutes);
bool readPicoPacket(uint8_t &type, uint8_t &key);
bool parseAckSeq(const String& body, uint32_t &outSeq);
bool postEventToPlugin(uint8_t eventNumber, uint8_t keyIndex, const char* pressKind, uint32_t heldMs, uint32_t seq, const char* extraJson);
bool servicePetTransitionQueue(uint32_t now);
bool checkFactoryResetHold();
void initButton(DebouncedButton& b);
void updateButton(DebouncedButton& b, uint32_t now);
bool isPressed(const DebouncedButton& b);
uint16_t crc16_ccitt(const uint8_t* data, size_t len);
void markSaveDirty();
void resetPet(bool firstBoot);
bool loadPet();
void savePetNow();
void serviceSave(uint32_t now);
void snapshotPet(PetSnapshot &out);
void resetPetEventQueue();
bool enqueuePetTransition(uint8_t code, uint8_t fromValue, uint8_t toValue);
void queueDeltaPair(uint8_t upCode, uint8_t downCode, uint8_t before, uint8_t after);
void detectAndQueuePetTransitions(const PetSnapshot &before, const PetSnapshot &after);
void syncPetTransitionBaseline();
void commitPetTransitions();
uint8_t stageFromAgeMinutes(uint16_t ageMinutes);
const char* stageName(uint8_t s);
void applyBounds();
void agePetByMinutes(uint16_t mins);
void simulatePetToNow(uint32_t now);
void performPetAction(PetAction action);
uint16_t moodColor(uint8_t v);
void drawBar(int x, int y, int w, uint8_t value, uint16_t color);
void drawHudLine(int row, const String& text, String& cache);
void clearPetArea();
void drawPoop(int x, int y);
void drawPetSprite();
void drawActionStrip();
void drawHudAndBars();
void renderPetUi(bool force);
void pushWrappedChat(const String& msgRaw);
void appendTextPageMessage(const String& msgRaw);
void showTextPage(uint32_t ttlMs);
void renderTextPage(bool force);
void serviceTextPage(uint32_t now);
void handleRoot();
void handleMsg();
void handleStatus();
void handleClear();
void handleUi();
String petStatusJson();
void handlePet();
void handleHealth();
void ensureWiFi(uint32_t now);
void drawBootSplash(const char* msg);
void fullUiInit();
void serviceButtons(uint32_t now);
void servicePetTiming(uint32_t now);
void servicePicoEvents();

// Small wrappers keep call sites tidy while avoiding duplicate default arguments
// in both prototypes and definitions, which older Arduino toolchains dislike.
inline bool postEventToPlugin(uint8_t eventNumber, uint8_t keyIndex, const char* pressKind, uint32_t heldMs, uint32_t seq) {
  return postEventToPlugin(eventNumber, keyIndex, pressKind, heldMs, seq, nullptr);
}
inline void resetPet() {
  resetPet(false);
}
inline void renderPetUi() {
  renderPetUi(false);
}

// ============================================================================
// 2. LOW-OVERHEAD HELPER FUNCTIONS
// ============================================================================
// Small helpers live here.
// They are intentionally tiny because this firmware calls them a lot.
// On an ESP8266, little utility functions like these help keep the code tidy
// without paying a big runtime penalty.
// ============================================================================

static inline uint16_t rgb565(uint8_t r, uint8_t g, uint8_t b) {
  return ((r & 0xF8) << 8) | ((g & 0xFC) << 3) | (b >> 3);
}

static inline uint32_t elapsedMs(uint32_t now, uint32_t since) {
  return now - since;
}

static inline int clampInt(int v, int lo, int hi) {
  return (v < lo) ? lo : (v > hi ? hi : v);
}

static inline uint8_t clampU8(int v, uint8_t lo, uint8_t hi) {
  if (v < (int)lo) return lo;
  if (v > (int)hi) return hi;
  return (uint8_t)v;
}

static inline uint16_t clampU16(int v, uint16_t lo, uint16_t hi) {
  if (v < (int)lo) return lo;
  if (v > (int)hi) return hi;
  return (uint16_t)v;
}

String truncateCols(const String& s) {
  if ((int)s.length() <= MAX_COLS) return s;
  return s.substring(0, MAX_COLS);
}

String urlDecode(const String& in) {
  String out;
  out.reserve(in.length());
  for (size_t i = 0; i < in.length(); i++) {
    char c = in[i];
    if (c == '+') {
      out += ' ';
    } else if (c == '%' && i + 2 < in.length()) {
      auto hexVal = [](char h) -> int {
        if (h >= '0' && h <= '9') return h - '0';
        if (h >= 'a' && h <= 'f') return 10 + (h - 'a');
        if (h >= 'A' && h <= 'F') return 10 + (h - 'A');
        return 0;
      };
      char decoded = (hexVal(in[i + 1]) << 4) | hexVal(in[i + 2]);
      out += decoded;
      i += 2;
    } else {
      out += c;
    }
  }
  return out;
}

String jsonFindString(const String& body, const String& key) {
  int k = body.indexOf("\"" + key + "\"");
  if (k < 0) return "";
  int colon = body.indexOf(':', k);
  if (colon < 0) return "";
  int q1 = body.indexOf('"', colon + 1);
  if (q1 < 0) return "";
  int q2 = body.indexOf('"', q1 + 1);
  if (q2 < 0) return "";
  return body.substring(q1 + 1, q2);
}

// ============================================================================
// 3. ONBOARD LED FEEDBACK
// ============================================================================
// The builtin LED is our tiny hardware heartbeat.
// We pulse it for button taps, ACK success/failure hints, and activity.
// The LED service is non-blocking: we set an expiry timestamp, then turn it
// back off later inside the main loop.
// ============================================================================

bool ledPulseActive = false;
uint32_t ledPulseUntil = 0;

void ledOn()  { digitalWrite(LED_BUILTIN, LOW); }
void ledOff() { digitalWrite(LED_BUILTIN, HIGH); }

void pulseLed(uint16_t ms) {
  ledOn();
  ledPulseActive = true;
  ledPulseUntil = millis() + ms;
}

void serviceLed(uint32_t now) {
  if (ledPulseActive && (int32_t)(now - ledPulseUntil) >= 0) {
    ledOff();
    ledPulseActive = false;
  }
}

// ============================================================================
// 4. HEADER / MESSAGE LAYER
// ============================================================================
// The TFT has a two-line header at the top.
//
// Line 1 priority:
//   transient toast > latest chat line > blank
//
// Line 2:
//   base status + last key event
//
// We cache what was previously drawn, so we do not redraw identical text.
// That cuts flicker and saves time.
// ============================================================================

String statusBase = "Boot...";
String lastKeyText = "K:--";
String transientStatus = "";
uint32_t transientUntilMs = 0;
String lastDrawLine1 = "";
String lastDrawLine2 = "";
String latestChat = "";

// ---------------------------------------------------------------------------
// Dedicated text page
// ---------------------------------------------------------------------------
// The pet UI is great for game data, but terrible for longer messages.
// So incoming text gets its own temporary full-screen page.
//
// Behavior:
// - Every new message is wrapped into multiple 26-character lines
// - New wrapped lines are appended to a small rolling history
// - The text page becomes visible for 2 seconds on new text
// - After the timeout, the display returns to the pet scene automatically
//
// This gives us a readable message view without permanently stealing the TFT.
String textPageLines[TEXT_PAGE_HISTORY_LINES];
uint8_t textPageLineCount = 0;
bool textPageActive = false;
uint32_t textPageUntilMs = 0;
uint32_t lastTextPageDrawToken = 0;

void drawLineArea(int y, const String& text) {
  tft.fillRect(0, y, SCREEN_W, LINE_H, COLOR_BG);
  tft.setCursor(0, y);
  tft.setTextColor(COLOR_FG, COLOR_BG);
  tft.print(truncateCols(text));
}

String computeLine1() {
  if (transientStatus.length()) return transientStatus;
  if (latestChat.length()) return latestChat;
  return "";
}

String computeLine2() {
  String line2 = statusBase;
  if (line2.length()) line2 += " ";
  line2 += lastKeyText;
  return line2;
}

void updateHeaderLine1(bool force = false) {
  String line1 = computeLine1();
  if (!force && line1 == lastDrawLine1) return;
  lastDrawLine1 = line1;
  drawLineArea(0, line1);
}

void updateHeaderLine2(bool force = false) {
  String line2 = computeLine2();
  if (!force && line2 == lastDrawLine2) return;
  lastDrawLine2 = line2;
  drawLineArea(LINE_H, line2);
}

void setToast(const String& msg, uint32_t ttlMs) {
  transientStatus = truncateCols(msg);
  transientUntilMs = millis() + ttlMs;
  if (!textPageActive) updateHeaderLine1(true);
}

void updateTransientStatus(uint32_t now) {
  if (transientStatus.length() && (int32_t)(now - transientUntilMs) >= 0) {
    transientStatus = "";
    if (!textPageActive) updateHeaderLine1(true);
  }
}

void clearUiMessages() {
  latestChat = "";
  transientStatus = "";
  transientUntilMs = 0;
  lastDrawLine1 = "";
  textPageLineCount = 0;
  textPageActive = false;
  textPageUntilMs = 0;
  lastTextPageDrawToken = 0;
  updateHeaderLine1(true);
}

void appendTextPageMessage(const String& msgRaw) {
  String clean = msgRaw;
  clean.replace("\r", " ");
  clean.replace("\n", " ");
  clean.trim();
  if (!clean.length()) return;

  int start = 0;
  while (start < (int)clean.length()) {
    int remaining = (int)clean.length() - start;
    int take = remaining > MAX_COLS ? MAX_COLS : remaining;

    if (remaining > MAX_COLS) {
      int split = -1;
      for (int i = start + take - 1; i > start; --i) {
        if (clean[i] == ' ') {
          split = i;
          break;
        }
      }
      if (split > start) take = split - start;
    }

    String line = clean.substring(start, start + take);
    line.trim();
    if (!line.length()) {
      start += take + 1;
      continue;
    }

    if (textPageLineCount < TEXT_PAGE_HISTORY_LINES) {
      textPageLines[textPageLineCount++] = line;
    } else {
      for (uint8_t i = 1; i < TEXT_PAGE_HISTORY_LINES; ++i) textPageLines[i - 1] = textPageLines[i];
      textPageLines[TEXT_PAGE_HISTORY_LINES - 1] = line;
    }

    start += take;
    while (start < (int)clean.length() && clean[start] == ' ') start++;
  }
}

void renderTextPage(bool force) {
  if (!textPageActive && !force) return;

  uint32_t token = (uint32_t)textPageLineCount ^ (textPageUntilMs << 1) ^ (uint32_t)textPageActive;
  if (!force && token == lastTextPageDrawToken) return;
  lastTextPageDrawToken = token;

  tft.fillScreen(COLOR_BG);
  tft.setTextWrap(false);
  tft.setTextSize(TEXT_SIZE);
  tft.setTextColor(COLOR_ACCENT, COLOR_BG);
  tft.setCursor(0, 0);
  tft.print("MESSAGES");
  tft.drawFastHLine(0, LINE_H, SCREEN_W, COLOR_DIM);

  tft.setTextColor(COLOR_FG, COLOR_BG);
  for (uint8_t i = 0; i < textPageLineCount && i < TEXT_PAGE_HISTORY_LINES; ++i) {
    tft.setCursor(0, (i + 1) * LINE_H);
    tft.print(textPageLines[i]);
  }
}

void showTextPage(uint32_t ttlMs) {
  textPageActive = true;
  textPageUntilMs = millis() + ttlMs;
  renderTextPage(true);
}

void serviceTextPage(uint32_t now) {
  if (!textPageActive) return;
  if ((int32_t)(now - textPageUntilMs) >= 0) {
    textPageActive = false;
    lastTextPageDrawToken = 0;
    renderPetUi(true);
  }
}
// ============================================================================
// 5. PICO SERIAL INPUT + ACK EVENT PATH
// ============================================================================
// The Pico speaks to the ESP using a tiny packet:
//   0xA5, type, key, checksum
//
// type == 1  -> key down
// type != 1  -> key up (release)
//
// Why this matters:
// - We want short vs long press detection
// - We want a compact serial format
// - We want corrupted packets to be ignored cleanly
//
// This section also contains the Lumia event sender.
// ============================================================================

uint32_t pressStart[KEY_COUNT] = {};
bool isDown[KEY_COUNT] = {};
bool picoSeen = false;
uint32_t seqCounter = 0;
uint32_t lastSeqSent = 0;
uint32_t lastAckSeq = 0;
bool lastPostOk = false;

// ----------------------------------------------------------------------------
// FUTURE REVISION SCAFFOLD 1: PET TELEMETRY / LUMIA VARIABLE SYNC
// ----------------------------------------------------------------------------
// Right now the firmware sends compact pet-change events as JSON posts.
//
// The next likely revision is a more formal telemetry contract between the ESP
// and a Lumia-side plugin. To make that future change painless, we define the
// ideas here in tutorial form:
//
// - Stable change IDs that should never shift once released
// - A compact packet shape for plugin-side variables
// - One obvious place to extend if we later add batching or checksums
//
// The current build still uses the existing JSON sender below, but these
// scaffolds explain where that future protocol should grow.
// ----------------------------------------------------------------------------

enum PetTelemetryField : uint8_t {
  PET_FIELD_HUNGER = 0,
  PET_FIELD_HAPPINESS,
  PET_FIELD_ENERGY,
  PET_FIELD_HYGIENE,
  PET_FIELD_HEALTH,
  PET_FIELD_DISCIPLINE,
  PET_FIELD_POOP,
  PET_FIELD_STAGE,
  PET_FIELD_SLEEPING,
  PET_FIELD_SICK,
  PET_FIELD_ALIVE
};

struct FuturePetTelemetryPacket {
  uint8_t changeCode;      // Stable event meaning, for example hunger_down
  uint8_t fieldId;         // Which tracked field changed
  uint8_t fromValue;       // Previous value
  uint8_t toValue;         // New value
  int8_t delta;            // Signed difference, handy for plugin variables
  uint16_t ageMinutes;     // Snapshot context for later Lumia-side logic
};
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
void loop() {
  uint32_t now = millis();

  server.handleClient();
  serviceLed(now);
  updateTransientStatus(now);
  serviceTextPage(now);
  ensureWiFi(now);
  serviceButtons(now);
  servicePicoEvents();
  servicePetTiming(now);
  servicePetTransitionQueue(now);
  serviceSave(now);

  yield();
}

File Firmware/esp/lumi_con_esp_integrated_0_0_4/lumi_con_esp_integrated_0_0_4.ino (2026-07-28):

/*
  Lumi-Con ESP8266 firmware v0.0.4
  --------------------------------
  Performance update: partial redraws.

  Behaviour/output intentionally unchanged vs v0.0.3:
  - Header is TWO lines:
      Line 1: transient/prompt ("ACK OK", "ACK FAIL", "1=LEG 2=ACK", etc.)
      Line 2: base status + last key (e.g. "IP:192.168.1.50 K:12L")
  - Transient expiry redraws immediately.
  - LED ticks on EVERY PRESS packet.
  - Mode selection is blocking (Key 1=LEGACY, Key 2=CONFIRMED).

  Endpoints unchanged:
    GET  /msg?t=...
    GET  /status?t=...
    GET  /clear
    POST /ui {"channel":"chat|status|clear","text":"..."}
    GET  /health
*/

#include <Arduino.h>
#include <ESP8266WiFi.h>
#include <ESP8266WebServer.h>
#include <WiFiManager.h>
#include <ESP8266HTTPClient.h>
#include <WiFiClient.h>

#include <Adafruit_GFX.h>
#include <Adafruit_ST7735.h>
#include <SPI.h>

// ===================== CONFIG =====================

// ---- Lumia plugin endpoint (PC running Lumia) ----
const char* PLUGIN_HOST = "192.168.1.87";
constexpr uint16_t PLUGIN_PORT = 8787;
const char* PLUGIN_SECRET = ""; // optional header X-Matrix-Secret

// ---- Device identity ----
static String deviceId;

// ---- Pico UART ----
constexpr uint32_t PICO_BAUD = 115200;
constexpr uint8_t KEY_COUNT = 36;
constexpr uint32_t LONG_PRESS_MS = 600;

// ---- Mode selection keys (from Pico matrix) ----
constexpr uint8_t MODE_KEY_LEGACY = 1;   // press Key 1
constexpr uint8_t MODE_KEY_CONFIRM = 2;  // press Key 2

// ---- Factory reset trigger ----
constexpr uint8_t FACTORY_RESET_KEY = 0;
constexpr uint32_t FACTORY_RESET_HOLD_MS = 1200;
constexpr uint32_t FACTORY_RESET_WINDOW_MS = 2500;

// ---- TFT pins ----
#define TFT_CS   D2
#define TFT_DC   D1
#define TFT_RST  -1
Adafruit_ST7735 tft = Adafruit_ST7735(TFT_CS, TFT_DC, TFT_RST);
#define ST7735_TAB INITR_GREENTAB

// ---- Screen layout ----
static const uint16_t BG = ST77XX_BLACK;
static const uint16_t FG = ST77XX_WHITE;

static const int SCREEN_W = 160;
static const int SCREEN_H = 128;

static const int CHAR_W = 6;
static const int LINE_H = 8;

static const int MAX_COLS  = SCREEN_W / CHAR_W;  // 26
static const int MAX_LINES = SCREEN_H / LINE_H;  // 16

static const int STATUS_LINES = 2;
static const int CHAT_LINES   = MAX_LINES - STATUS_LINES; // 14

// Y positions
static const int Y_LINE1 = 0;
static const int Y_LINE2 = LINE_H;
static const int Y_CHAT  = STATUS_LINES * LINE_H;
static const int CHAT_H  = CHAT_LINES * LINE_H;

// ===================== GLOBALS =====================

ESP8266WebServer server(80);

String chatBuf[CHAT_LINES];
int chatCount = 0;

// Line 2 base status (IP, etc.)
String statusBase = "";

// last key (shown on line 2)
String lastKeyText = "K:--";

// Line 1 transient/prompt/status
String transientStatus = "";
uint32_t transientUntilMs = 0;

// caches for “draw only if changed”
String lastDrawLine1 = "";
String lastDrawLine2 = "";

uint32_t pressStart[KEY_COUNT] = {};
bool isDown[KEY_COUNT] = {};

bool picoSeen = false;

uint32_t seqCounter = 0;
uint32_t lastSeqSent = 0;
uint32_t lastAckSeq = 0;
bool lastPostOk = false;

enum ReliabilityMode { MODE_LEGACY, MODE_CONFIRMED };
ReliabilityMode reliabilityMode = MODE_LEGACY;

// ===================== LED HELPERS (ESP8266 LED is active-low) =====================

void ledOn()  { digitalWrite(LED_BUILTIN, LOW); }
void ledOff() { digitalWrite(LED_BUILTIN, HIGH); }

void blink(uint8_t times, uint16_t onMs, uint16_t offMs) {
  for (uint8_t i = 0; i < times; i++) {
    ledOn();  delay(onMs);
    ledOff(); delay(offMs);
    yield();
  }
}

// Quick “tick blink” for press feedback
void blinkPressTick() {
  ledOn();  delay(12);
  ledOff(); delay(8);
}

// ===================== TEXT HELPERS =====================

String urlDecode(const String& in) {
  String out;
  out.reserve(in.length());
  for (size_t i = 0; i < in.length(); i++) {
    char c = in[i];
    if (c == '+') out += ' ';
    else if (c == '%' && i + 2 < in.length()) {
      auto hexVal = [](char h) -> int {
        if (h >= '0' && h <= '9') return h - '0';
        if (h >= 'a' && h <= 'f') return 10 + (h - 'a');
        if (h >= 'A' && h <= 'F') return 10 + (h - 'A');
        return 0;
      };
      char decoded = (hexVal(in[i + 1]) << 4) | hexVal(in[i + 2]);
      out += decoded;
      i += 2;
    } else out += c;
  }
  return out;
}

String truncateCols(const String& s) {
  if ((int)s.length() <= MAX_COLS) return s;
  return s.substring(0, MAX_COLS);
}

// ===================== DISPLAY (PARTIAL REDRAW) =====================

void drawLineArea(int y, const String& text) {
  // clear this line area, then print
  tft.fillRect(0, y, SCREEN_W, LINE_H, BG);
  tft.setCursor(0, y);
  tft.print(truncateCols(text));
}

// computed header line strings (exactly matching v0.0.3 output)
String computeLine1() {
  return transientStatus.length() ? transientStatus : "";
}

String computeLine2() {
  String line2 = statusBase;
  if (line2.length()) line2 += " ";
  line2 += lastKeyText;
  return line2;
}

void updateHeaderLine1(bool force = false) {
  String line1 = computeLine1();
  if (!force && line1 == lastDrawLine1) return;
  lastDrawLine1 = line1;
  drawLineArea(Y_LINE1, line1);
}

void updateHeaderLine2(bool force = false) {
  String line2 = computeLine2();
  if (!force && line2 == lastDrawLine2) return;
  lastDrawLine2 = line2;
  drawLineArea(Y_LINE2, line2);
}

void redrawChatRegion() {
  // clear chat region only, then redraw chat text exactly as before
  tft.fillRect(0, Y_CHAT, SCREEN_W, CHAT_H, BG);

  const int visible = CHAT_LINES;
  const int startIndex = (chatCount > visible) ? (chatCount - visible) : 0;
  const int linesToDraw = chatCount - startIndex;

  int yStart = Y_CHAT + (CHAT_H - (linesToDraw * LINE_H));
  if (yStart < Y_CHAT) yStart = Y_CHAT;

  int y = yStart;
  for (int i = startIndex; i < chatCount; i++) {
    tft.setCursor(0, y);
    tft.print(truncateCols(chatBuf[i]));
    y += LINE_H;
    if (y >= SCREEN_H) break;
  }
}

void fullRedraw() {
  // Used only at key moments (boot/major transitions). Output matches v0.0.3.
  tft.fillScreen(BG);
  // reset caches so header reprints even if content same
  lastDrawLine1 = "__force__";
  lastDrawLine2 = "__force__";
  updateHeaderLine1(true);
  updateHeaderLine2(true);
  redrawChatRegion();
}

// ===================== TRANSIENT STATUS HELPERS =====================

void setTransientStatus(const String& msg, uint32_t ttlMs) {
  transientStatus = msg;
  transientUntilMs = millis() + ttlMs;
}

void updateTransientStatus() {
  if (!transientStatus.length()) return;

  if ((int32_t)(millis() - transientUntilMs) >= 0) {
    transientStatus = "";
    // v0.0.3 did a full redraw; v0.0.4 redraws only affected line (same visible output)
    updateHeaderLine1(true);
  }
}

// ===================== CHAT BUFFER =====================
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

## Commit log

2026-03-27 Delete Docs/Schematic.pdf
    wiring was backwards for key matrix
2026-07-28 Add LumiCon 6x6 Mini build releases
    [6X6 Front V2_reference.stl, BOM.csv, LumiCon_6x6_Hotswap_R5_4_Branded_Clean.kicad_pcb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]
2026-07-28 Clarify phone-based device setup
